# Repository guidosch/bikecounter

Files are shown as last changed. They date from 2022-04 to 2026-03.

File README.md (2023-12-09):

# BikeCounter  <!-- omit in toc -->



This repository contains the hardware and software components of a [PIR](https://en.wikipedia.org/wiki/Passive_infrared_sensor) based tracking device to monitor the usage of local bike trails. The data is sent over [LoRaWAN](https://de.wikipedia.org/wiki/Long_Range_Wide_Area_Network) to [TTN](https://www.thethingsnetwork.org/) and from there to a [Google Cloud](https://console.cloud.google.com) backend which stores the data and provides api endpoints for the data visualization web UI ([bikeCounterUI](https://github.com/guidosch/bikecounterUI)).

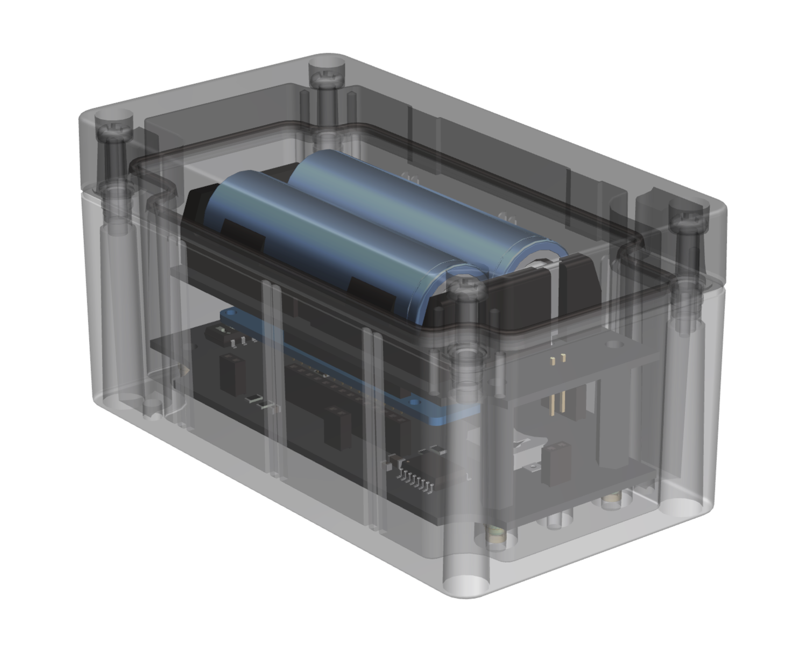
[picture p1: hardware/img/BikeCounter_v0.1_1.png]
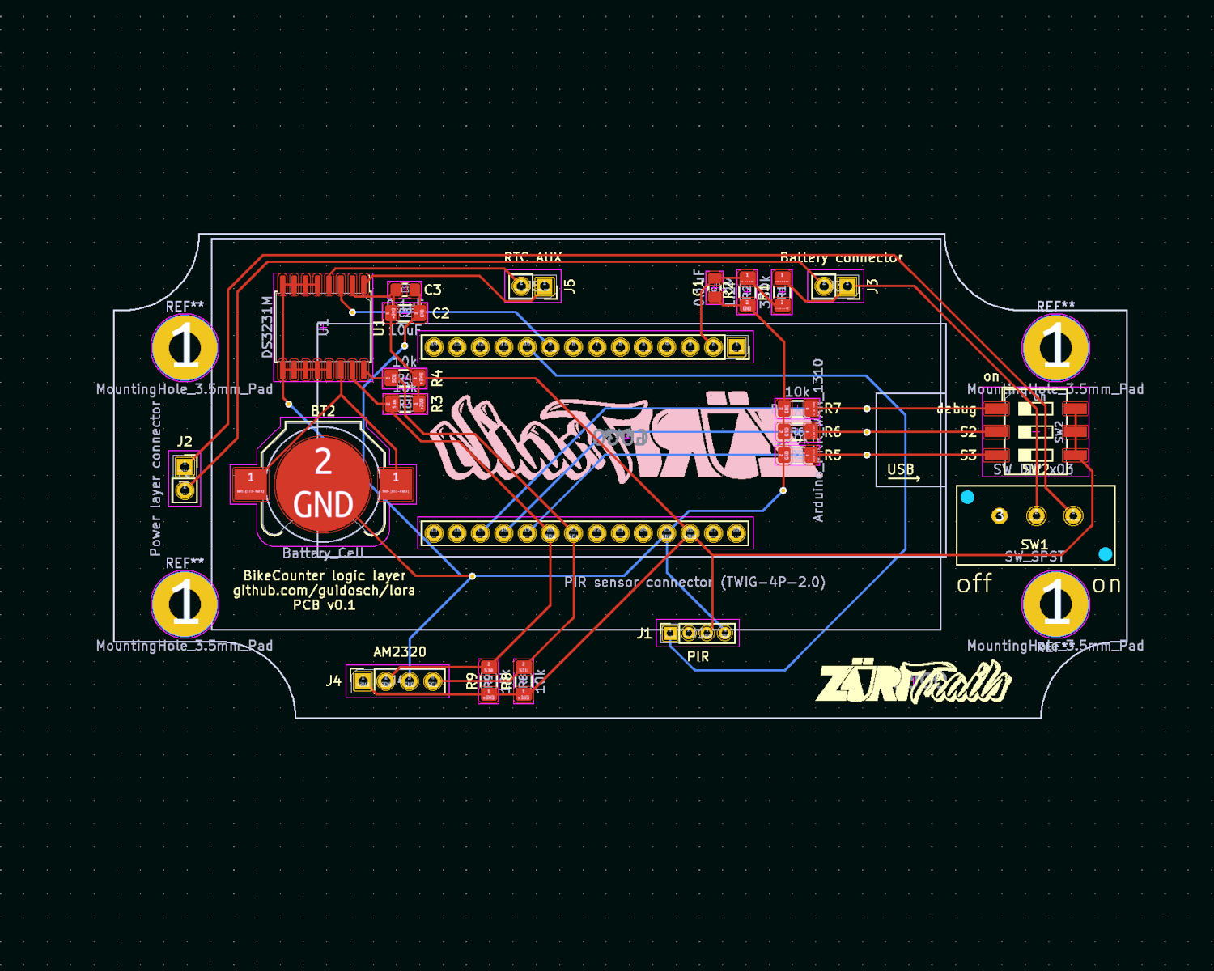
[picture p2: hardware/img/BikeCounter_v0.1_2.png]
 
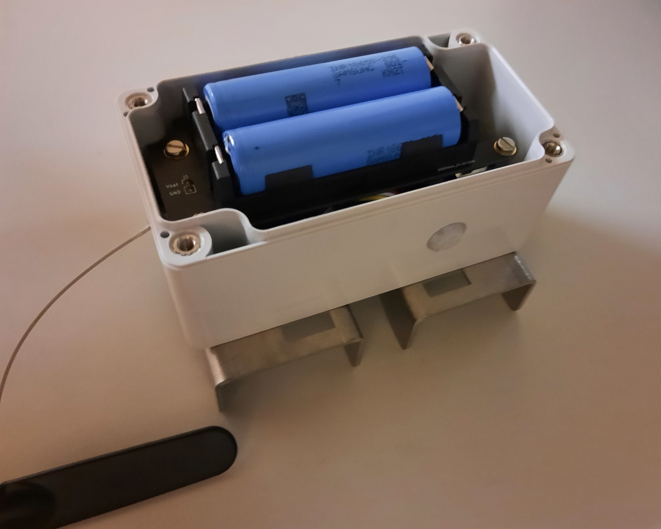
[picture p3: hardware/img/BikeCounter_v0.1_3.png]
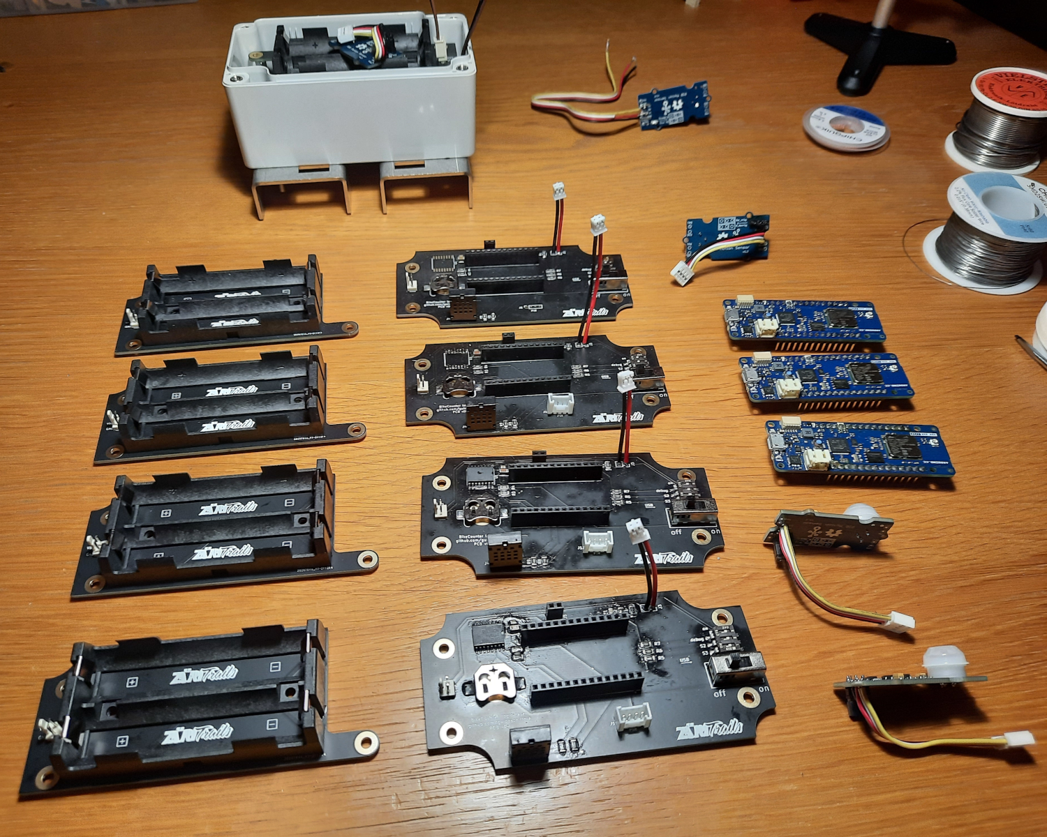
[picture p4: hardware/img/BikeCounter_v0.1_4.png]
 

The repository is divided into two main sections. The first one contains all the data regarding the hardware components and the second one holds the software code.

- [Hardware](#hardware)
- [Software](#software)
  - [Overview](#overview)
  - [BikeCounter](#bikecounter)
    - [Overall state machine](#overall-state-machine)
    - [Data package](#data-package)
    - [Time scheduler](#time-scheduler)
    - [Device configuration](#device-configuration)
    - [Unit tests](#unit-tests)
    - [To be aware of](#to-be-aware-of)
  - [TTN](#ttn)
  - [Google Cloud](#google-cloud)
- [Contributing](#contributing)
- [License](#license)

# Hardware

The core component of the device is an [Arduino MRKWAN 1310](https://docs.arduino.cc/hardware/mkr-wan-1310) which sits on the "logic layer" PCB. This PCB connects the micro controller to the sensors, the dip switches and the "power layer" PCB.

To detect the movement a PIR sensor from [Seeed Studio](https://www.seeedstudio.com/Grove-PIR-Motion-Sensor.html) is used and to monitor the internal environment of the device a temperature and humidity sensor from [Adafruit](https://www.adafruit.com/product/3721) was chosen.

The "power layer" PCB holds two rechargeable lithium-ion batteries (18650). This allows the device to run up to one year without exchanging the batteries.

The schematics and layout files of the PCBs as well as the BOM of the whole device can be found in the corresponding subfolder.

# Software

This Repository contains the code for the tracking device as well as the scripts running on the backend.

## Overview

```mermaid
flowchart LR;
  subgraph BikeCounter;
    Biker(Round) -->|infrared radiation| PIR-sensor;
    PIR-sensor -->|DIO| Arduino-MKRWAN-1310;
    Temp&Hum-sensor -->|I2C| Arduino-MKRWAN-1310;
    DIP-switches -->|DIO| Arduino-MKRWAN-1310;
  end; 
  subgraph TTN;   
    Arduino-MKRWAN-1310 -->|LoRaWAN| PayloadFormatter;
  end;  
  subgraph Google Cloud;
    PayloadFormatter -->|webhook| Cloud-function;
    Cloud-function --> firebase;
  end;
```

## BikeCounter

There are two versions of the main BikeCounter software. The **light** version is a simple and basic implementation of the needed functionality. The **pro** version has extended features that allow it to take track of time as well as its environnement conditions.

(Due to the fact that the light version is almost obsolete only the pro version will be explained in more detail.)

### Overall state machine

```mermaid
stateDiagram-v2
    m1: main loop
    [*] --> Setup
    Setup --> m1
    state m1 {
      state if_motion <<choice>>
      s0: motion detected ?
      s1: store information in variable      
      s2: timer called
      s3: threshold reached ?
      state if_threshold <<choice>>
      s4: send data
      state if_downlink <<choice>>
      s5: downlink received ?
      s6: correct rtc drift
      
      [*] --> s0
      s0 --> if_motion
      if_motion --> s1: true
      if_motion --> s2: false
      s2 --> s4
      s1 --> s3
      s3 --> if_threshold
      if_threshold --> deepSleep: false
      if_threshold --> s4: true
      s4 --> s5
      s5 --> if_downlink
      if_downlink --> deepSleep: false
      if_downlink --> s6: true
      s6 --> deepSleep
      deepSleep --> [*]
    }
```

After the main loop finishes the device goes into a deepSleep mode. From there the PIR sensor or the rtc timer can wake it back up and trigger the main loop again.

### Data package

The payload size of one single LoRaWAN data package is restricted to 51 bytes. To avoid multi-package messages and to reduce transmission time an optimized information transmission protocol was developed.

The dataPackage class handles all the information conversion and encoding. A detailed documentation of the protocol can be found in the dataPackage.xlsx file.

**Payload encoding**

| address<br>bits | 0-7<br>[8] | 8-11<br>[4] | 12-15<br>[4] | 16-18<br>[3] | 19-23<br>[5] | 24-27<br>[5] | 28-30<br>[3] | 31-54<br>[24] | 55-57<br>[3] | 58-62<br>[5] | 63-408<br>[6/7/8/9/10] |
| --- | --- | --- | --- | --- | --- | --- | --- | --- | --- | --- | --- |
| **content** | count | software version | hardware version | status index | battery voltage | temperature  | humidity | device time | interval index | hour of the day | offset minutes array |

The data type size of the offset array depends on the selected interval.

### Time scheduler

During the night as well as the cold seasons of the year the data transmission interval can be adjusted to save energy and transmission time. The timeScheduler class provides all the necessary methods to accomplish such a dynamic behavior.

### Device configuration

The configuration information to establish a connection to the TTN (AppEUI and AppKey) is saved to the flash memory of the Arduino MKRWAN 1310. The `writeConfigToFlash.ino` script saves a new configuration to the memory.

### Unit tests

This repository contains serval unit tests for the dataPackage and the timeScheduler class. The tests are written using the [Google Test](https://google.github.io/googletest/) framework. A cMake configuration for local testing is provided as well as an automated CI pipeline for the master branch. The `runTestsLocal.sh` script executes all the commands needed to run the unit tests locally.

### To be aware of

- The LoRa module is very timing sensitive. That is the reason there are so many delays in the code to give it enough time to wait for messages and to response.

- The first time the (deep)sleep method is called, it re-initializes the RTC to a wrong value. To fix this issue the first iteration of the main loop puts the device into the sleep mode for a short period of time and resets the RTC in the next loop.

## TTN

The message from the device gets over LoRaWAN to the TTN server where a uplink payload formatter parses the data bytes to a human readable JavaScript object. The server then triggers a webhook and passes the data object to the Google Cloud function API endpoint.

The downlink message with the time drift information will also be parsed by the payload formatter defined in TTN.

The up/down-link payload formatter scripts are stored in the TTN subfolder.

## Google Cloud

The triggered cloud function evaluates the data object sent from TTN and saves it to the Firebase database. Depending on the difference between the local time of the device and the server time it schedules a downlink message to correct the internal device time.

There are also cloud functions that provide an API endpoint for the web UI ([bikeCounterUI](https://github.com/guidosch/bikecounterUI)) to visualize the stored data.

# Setup IDE and compile code
Download and install: `arduino-cli` which is available for brew or apt-get. Install the `arduino` extension for VSCode and adjust the `arduino.path` in the extension settings and point to your arduino-cli installation folder.

Add the following libraries to your installation: `arduino-cli lib install [libName]`

- Needed libraries:
  - MKRWAN@1.1.0
  - RTCZero@1.6.0
  - SPI.h --> already preinstalled
  - SparkFun SPI SerialFlash Arduino Library@1.0.3
  - Arduino Low Power@1.2.2
  - Adafruit Unified Sensor@1.1.6

Copy and adjust the `.vscode/c_cpp_properties.json_example` for your platform. You have to adjust the place where arduino-cli downloads the libraries as they are needed by the IDE

Compile: `arduino-cli compile --fqbn arduino:samd:mkrwan1310 BikeCounterPro.ino`

Deploy: `arduino-cli upload -p [/dev/yourdevice] --fqbn arduino:samd:mkrwan1310 BikeCounterPro.ino`

Hint: `arduino-cli board list` will show the USB port, where the device is connected

# Contributing

Pull requests are welcome. For major changes, please open an issue first to discuss what you would like to change.

Please make sure to update the tests as appropriate.

# License

This project is licensed under [CC0-1.0](LICENSE)

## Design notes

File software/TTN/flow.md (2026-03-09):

# Flow from Device to TTN

1. Device sends data to TTN via LoRaWAN as uplink message encoded in bytes.
2. TTN receives the uplink message and processes it via the payload formatter (uplink)
3. The result is forwarded to GCP cloud function: See uplink_example.js for an example of the processed data.

# Flow from TTN to Device

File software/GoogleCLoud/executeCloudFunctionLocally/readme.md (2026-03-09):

# Execute Cloud Function Locally

## Setup

1. **Install dependencies:**
   ```bash
   npm install
   ```

2. **Download the Firebase/Google Cloud service account key:**
   - Go to the [Google Cloud Console](https://console.cloud.google.com/)
   - Navigate to **IAM & Admin → Service Accounts**
   - Select your project and the service account used by your Cloud Function
   - Click **Keys → Add Key → Create new key → JSON**
   - Save the downloaded file as `service-account-key.json` in this directory

3. **Run the function locally:**
   ```bash
   npm run start
   ```
   The function will be available at `http://localhost:8080/`

4. **Test with a sample request:**
Use the requests.http file which contains a test request (need vs code plugin: 
humao.rest-client). May adjust the playload by extacting it from the GCP functions log and paste it into file `payload-example.json`

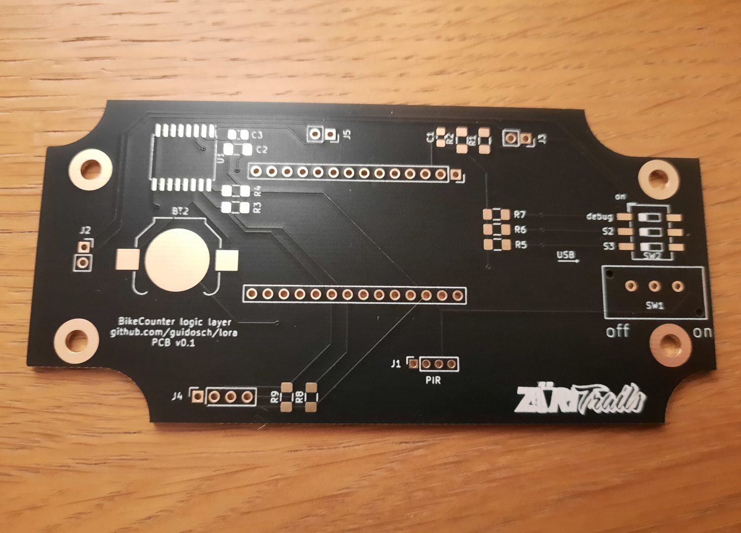
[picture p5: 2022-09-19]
hardware/img/BikeCounter_v0.1_5.png

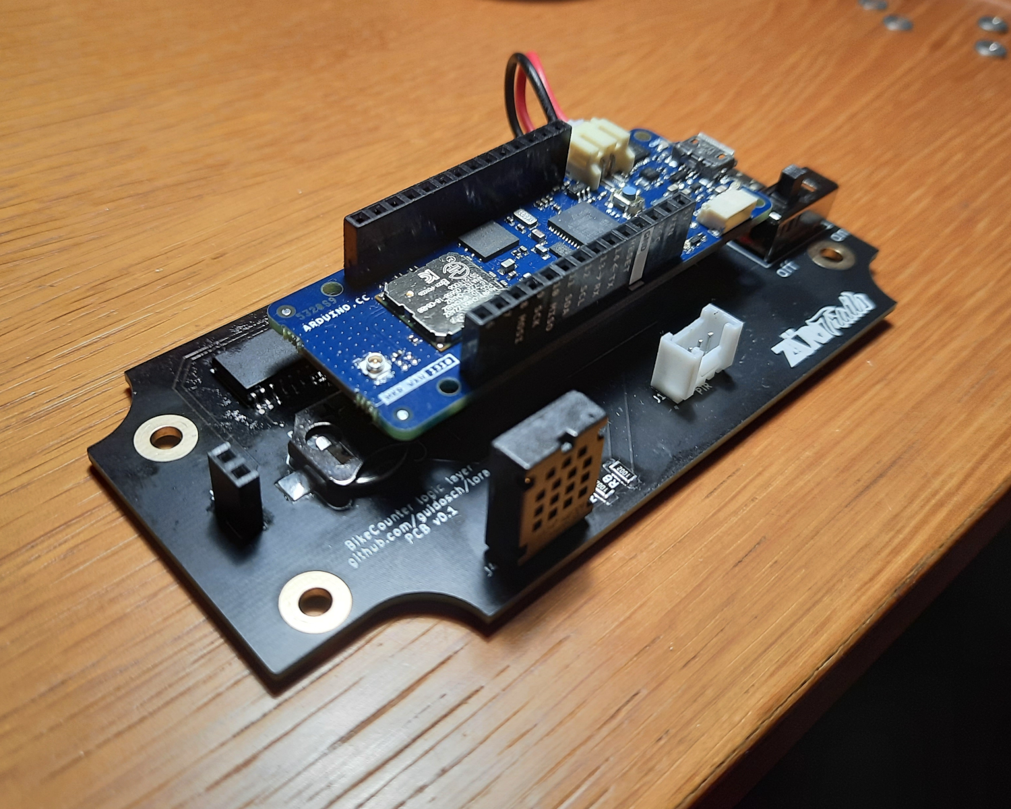
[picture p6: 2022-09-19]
hardware/img/BikeCounter_v0.1_6.png

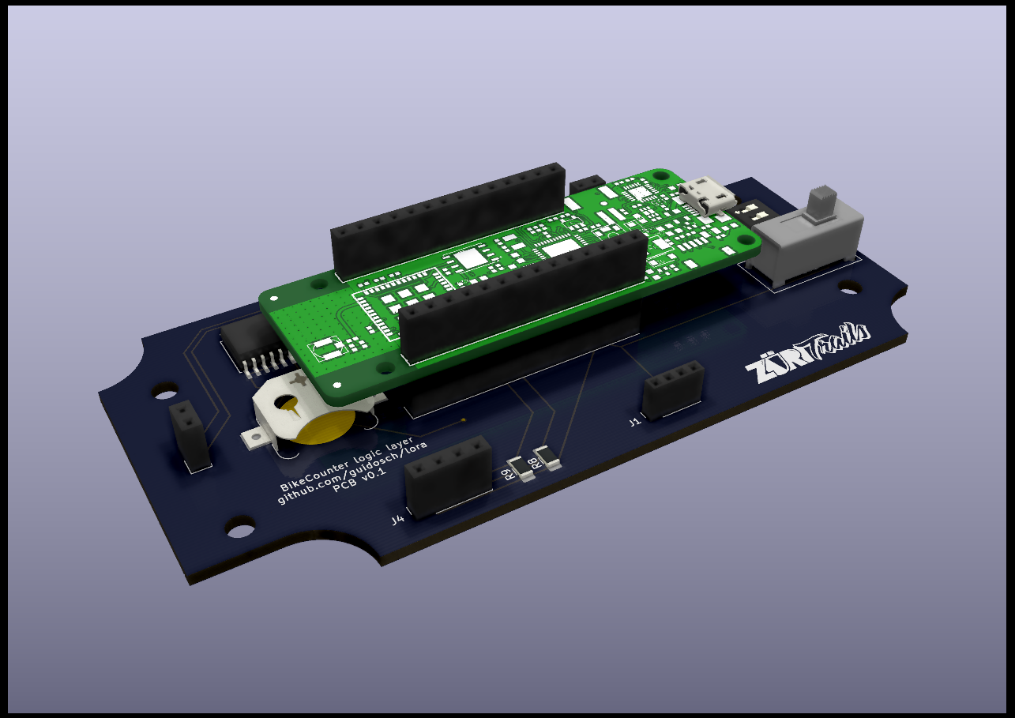
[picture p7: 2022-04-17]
hardware/PCB/LogicLayer/BikeCounter_LogicLayer_v0.1_r1_p1.png

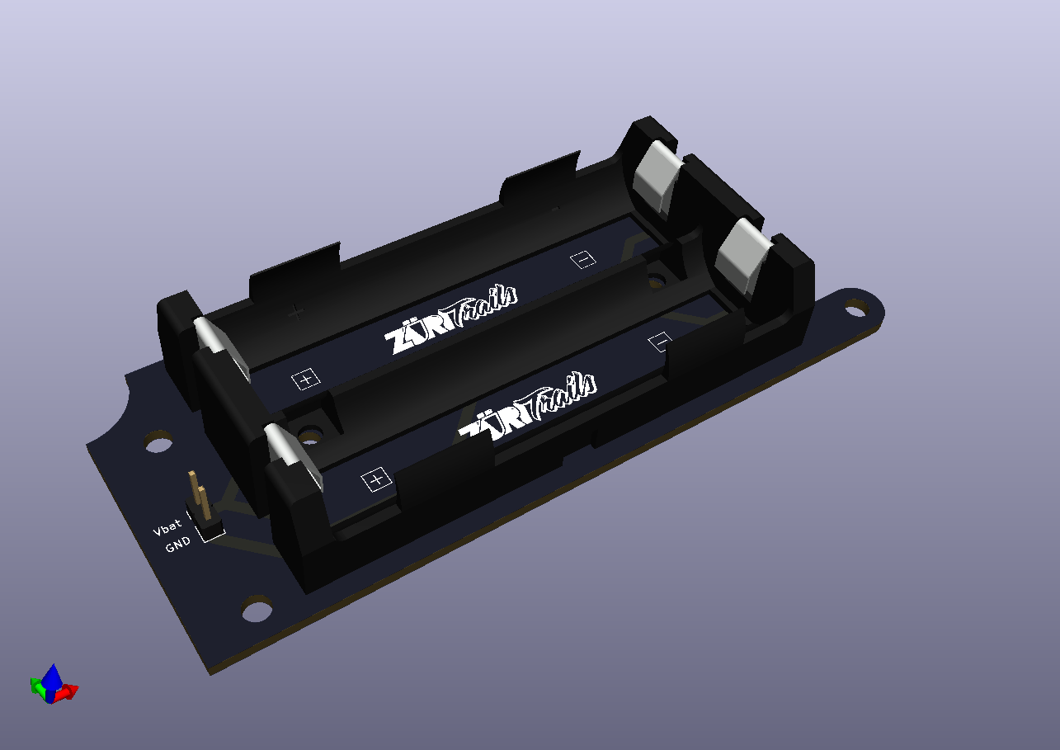
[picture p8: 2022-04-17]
hardware/PCB/PowerLayer/BikeCounter_PowerLayer_v0.1_r1_p1.png

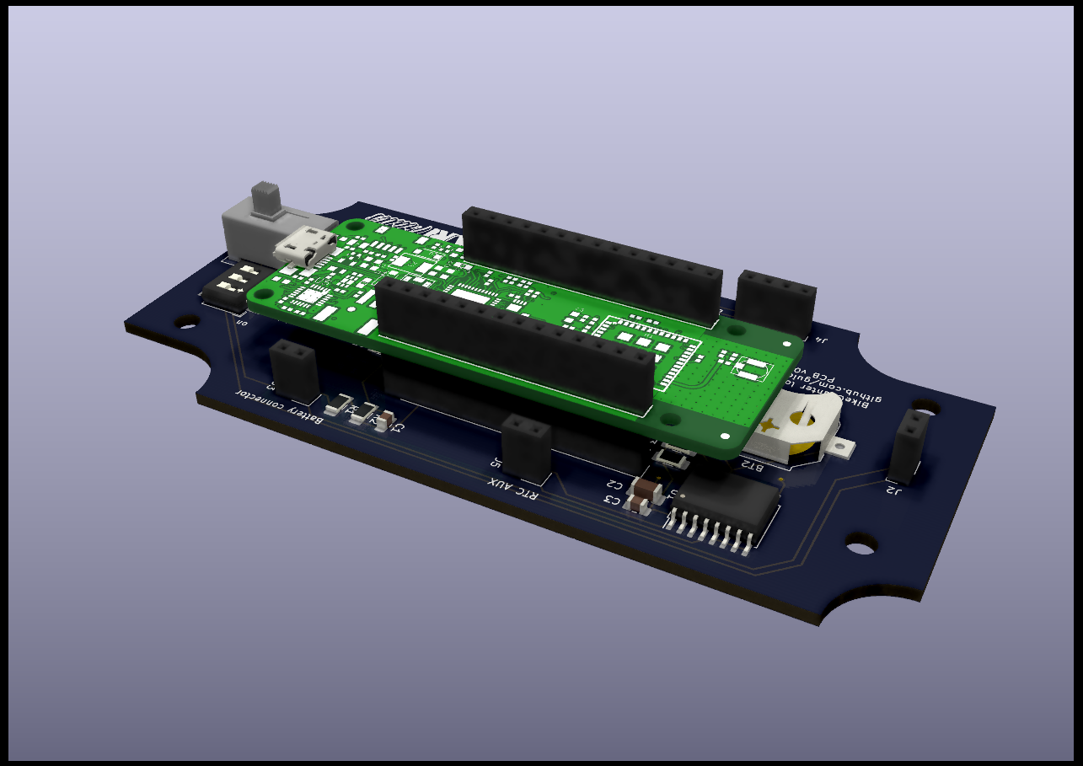
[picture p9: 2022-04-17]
hardware/PCB/LogicLayer/BikeCounter_LogicLayer_v0.1_r1_p3.png

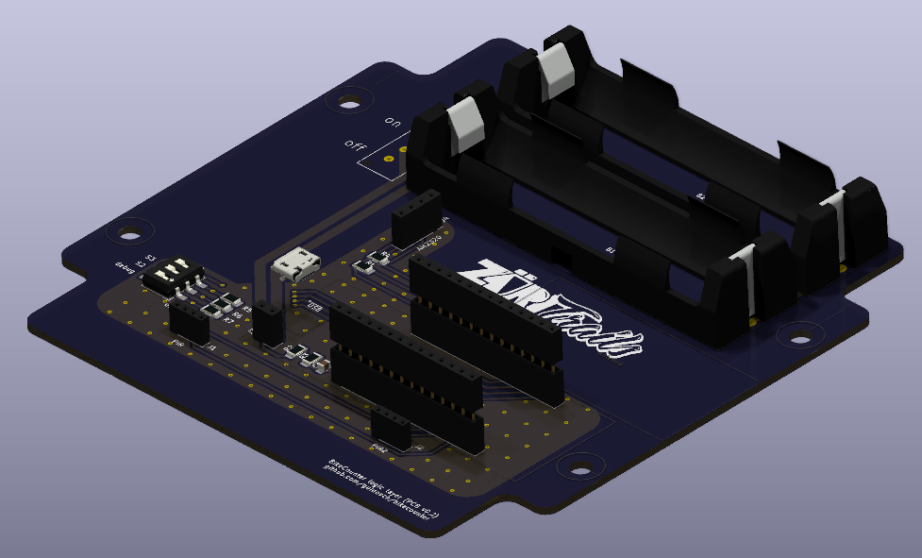
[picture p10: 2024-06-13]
hardware/PCB/SingleBoard/BikeCounter_SingleBoard.png

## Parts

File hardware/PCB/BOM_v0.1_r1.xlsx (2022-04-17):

Id | Designator | Package | Quantity | Designation | Price |  | Link 1 | Link 2 | Link 3
1 | R5,R9,R8,R7,R6,R4,R3 | R_1206_3216Metric_Pad1.42x1.75mm_HandSolder | 7 | 10k | 0.65 CHF | 4.55 CHF | https://www.mouser.ch/ProductDetail/Bourns/CHP1206AFX-1002ELF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
2 | BT2 | BatteryHolder_Keystone_3000_1x12mm | 1 | Battery_Cell | 0.62 CHF | 0.62 CHF | https://www.mouser.ch/ProductDetail/Keystone-Electronics/3000?qs=sGAEpiMZZMvxX9Q80wbhCYuFHF%2FXyzv7
3 | A1 | Arduino_MKR_WAN_1310 | 1 | Arduino_MKR_WAN_1310 | 47.17 CHF | 47.17 CHF | https://www.distrelec.ch/de/arduino-mkr-wan-1310-arduino-abx00029/p/30163021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
4 |  | Antenne | 1 |  | 5.18 CHF | 5.18 CHF | https://www.distrelec.ch/de/gsm-antenne-2g-3g-4g-fl-klebebefestigung-arduino-x000016/p/30101972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
5 | J1 | PinSocket_1x04_P2.00mm_Vertical | 1 | PIR sensor connector (TWIG-4P-2.0) | 0.17 CHF | 0.17 CHF | https://www.seeedstudio.com/Grove-Universal-4-pin-connector.html
6 | J5 | PinSocket_1x02_P2.54mm_Vertical | 1 | RTC AUX | 0.77 CHF | 0.77 CHF | https://www.mouser.ch/ProductDetail/Harwin/M20-7820242?qs=WS5Jv%252B%252Bx1qUrSLY%252BudG7mQ%3D%3D
7 | SW1 | Switch_MHS12204 | 1 | SW_SPST | 1.06 CHF | 1.06 CHF | https://www.mouser.ch/ProductDetail/TE-Connectivity-Alcoswitch/MHS12204?qs=x%2FgbKjZ2T%2FPUluB%2FWhqq0Q%3D%3D
8 | J2 | PinSocket_1x02_P2.54mm_Vertical | 1 | Power layer connector | 0.77 CHF | 0.77 CHF | https://www.mouser.ch/ProductDetail/Harwin/M20-7820242?qs=WS5Jv%252B%252Bx1qUrSLY%252BudG7mQ%3D%3D
9 | R2 | R_1206_3216Metric_Pad1.42x1.75mm_HandSolder | 1 | 1.2M | 0.21 CHF | 0.21 CHF | https://www.mouser.ch/ProductDetail/YAGEO/RT1206FRE071M2L
10 | R1 | R_1206_3216Metric_Pad1.42x1.75mm_HandSolder | 1 | 330k | 0.13 CHF | 0.13 CHF | https://www.mouser.ch/ProductDetail/Susumu/RG3216P-3303-D-T5?qs=nCAm%252BcMdy9yoDulF%2FHMGvA%3D%3D
11 | C1,C3 | C_0805_2012Metric_Pad1.15x1.40mm_HandSolder | 2 | 0.1uF | 0.12 CHF | 0.24 CHF | https://www.mouser.ch/ProductDetail/KEMET/C0805C104K5RAC7411 | https://www.mouser.ch/ProductDetail/Murata-Electronics/GCJ31CD7YA106KE02L?qs=DPoM0jnrROWHhAptP6iQ0Q%3D%3D
12 | U1 | SOIC-16W_7.5x10.3mm_P1.27mm | 1 | DS3231M | 10.70 CHF | 10.70 CHF | https://www.mouser.ch/ProductDetail/Maxim-Integrated/DS3231SN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 | https://www.digikey.ch/de/products/detail/analog-devices-inc-maxim-integrated/DS3231SN/1197576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
13 | SW2 | SW_DIP_SPSTx03_Slide_6.7x9.18mm_W8.61mm_P2.54mm_LowProfile | 1 | SW_DIP_x03 | 0.68 CHF | 0.68 CHF | https://www.mouser.ch/ProductDetail/CTS-Electronic-Components/219-3LPS?qs=6E8igxPflKd33iZv5eBb9Q%3D%3D
14 | C2 | C_1206_3216Metric_Pad1.33x1.80mm_HandSolder | 1 | 10uF | 1.35 CHF | 1.35 CHF | https://www.mouser.ch/ProductDetail/TDK/C3216X6S2A106K160AC
15 | B1 | BatteryHolder_Keystone_1049_2x18650 | 1 | Keystone_1049 | 5.83 CHF | 5.83 CHF | https://www.mouser.ch/ProductDetail/Keystone-Electronics/1049?qs=%2F7TOpeL5Mz78b0pqEFIl5w%3D%3D
16 | J1 | PinHeader_1x02_P2.54mm_Vertical | 1 | Logic layer connection | 0.38 CHF | 0.38 CHF | https://www.mouser.ch/ProductDetail/Samtec/TSW-102-19-L-S?qs=rU5fayqh%252BE00YQR0mRO7Kw%3D%3D
17 |  | PinSocket_1x14_P2.54mm_Vertical | 2 |  | 1.54 CHF | 3.08 CHF | https://www.mouser.ch/ProductDetail/Harwin/M20-7821446?qs=Jph8NoUxIfX%2FjYzLF0Toqw%3D%3D
18 |  | Casing | 1 |  | 18.63 CHF | 18.63 CHF | https://www.mouser.ch/ProductDetail/Hammond/1554D2GYSL?qs=8GnAp0dDS0IydYdPUJXAZg%3D%3D | https://www.mouser.ch/ProductDetail/Hammond/1554D2GYCL?qs=Tc%252BHE9vUsnsrPWXgdbccVQ%3D%3D | https://www.digikey.ch/de/products/detail/1554D2GYSL/HM3459-ND/2359931?itemSeq=385358295
19 |  | Mounting | 3 |  | 0.54 CHF | 1.62 CHF | https://www.mouser.ch/ProductDetail/Wurth-Elektronik/971220321?qs=wr8lucFkNMXKaoSdjnz3%252Bg%3D%3D
20 |  | Grove PIR sensor | 1 |  | 12.60 CHF | 12.60 CHF | https://www.distrelec.ch/de/grove-pir-bewegungssensor-seeed-studio-101020020/p/30069806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
21 |  | AM2320 | 1 |  | 4.52 CHF | 4.52 CHF | https://www.distrelec.ch/de/digitaler-temperatur-und-feuchtigkeitssensor-am2320-5v-adafruit-3721/p/30139175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
22 |  | Power Layer PCB | 1 |  | 4.78 | 4.78 CHF |  | JLCPCB
23 |  | Logic Layer PCB | 1 |  | 4.88 | 4.88 CHF |  | JLCPCB
24 |  | USB Kabel | 1 |  | 2.02 CHF | 2.02 CHF | https://www.reichelt.com/ch/de/usb-2-0-kabel-a-stecker-auf-90-micro-b-stecker-1-8-m-goobay-95343-p286822.html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
25 |  | Akku | 2 |  | 12.95 CHF | 25.90 CHF | https://www.conrad.ch/de/p/samsung-inr18650-29e-spezial-akku-18650-flat-top-hochtemperaturfaehig-li-ion-3-6-v-2900-mah-2239492.html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
 |  |  |  |  |  | 157.85 CHF

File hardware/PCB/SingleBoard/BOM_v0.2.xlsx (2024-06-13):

Id | Designator | Package | Quantity | Designation | Price |  | Link 1 | Link 2 | Link 3
1 |  | PCB | 1 | JLC PCB (20 Stk.) | 3.56 CHF | 3.56 CHF
2 | A1 | Arduino_MKR_WAN_1310 | 1 | Arduino_MKR_WAN_1310 | 39.44 CHF | 39.44 CHF | https://www.mouser.ch/ProductDetail/Arduino/ABX00029?qs=rkhjVJ6%2F3EJR8pfu7j970Q%3D%3D
3 | B1,B2 | BatteryHolder_Keystone_1043_1x18650 | 2 |  | 2.15 CHF | 4.30 CHF | https://www.mouser.ch/ProductDetail/Keystone-Electronics/1043?qs=%2F7TOpeL5Mz6j%2FnxeOA1rsg%3D%3D
 | C1 | Capacitor_SMD:C_0805_2012Metric_Pad1.18x1.45mm_HandSolder | 2 | 0.1uF | 0.06 CHF | 0.11 CHF | https://www.mouser.ch/ProductDetail/KEMET/C0805C104K5RAC7411 | https://www.mouser.ch/ProductDetail/Murata-Electronics/GCJ31CD7YA106KE02L?qs=DPoM0jnrROWHhAptP6iQ0Q%3D%3D
 | R1,R4,R5,R6,R7 | Resistor_SMD:R_1206_3216Metric_Pad1.30x1.75mm_HandSolder | 5 | 10k | 0.19 CHF | 0.93 CHF | https://www.mouser.ch/ProductDetail/Bourns/CHP1206AFX-1002ELF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
 | R2 | Resistor_SMD:R_1206_3216Metric_Pad1.30x1.75mm_HandSolder | 1 | 330k | 0.12 CHF | 0.12 CHF | https://www.mouser.ch/ProductDetail/Susumu/RG3216P-3303-D-T5?qs=nCAm%252BcMdy9yoDulF%2FHMGvA%3D%3D
 | R3 | Resistor_SMD:R_1206_3216Metric_Pad1.30x1.75mm_HandSolder | 1 | 1.2M | 0.14 CHF | 0.14 CHF | https://www.mouser.ch/ProductDetail/YAGEO/RT1206FRE071M2L
 | SW1 | General_TM:Switch_MHS12204 | 1 | SW_SPST | 0.73 CHF | 0.73 CHF | https://www.mouser.ch/ProductDetail/TE-Connectivity-Alcoswitch/MHS12204?qs=x%2FgbKjZ2T%2FPUluB%2FWhqq0Q%3D%3D
 | SW2 | Button_Switch_SMD:SW_DIP_SPSTx03_Slide_6.7x9.18mm_W8.61mm_P2.54mm_LowProfile | 1 | SW_DIP_x03 | 0.51 CHF | 0.51 CHF | https://www.mouser.ch/ProductDetail/CTS-Electronic-Components/219-3LPS?qs=6E8igxPflKd33iZv5eBb9Q%3D%3D
 | J1,J2 | Connector_PinSocket_2.00mm:PinSocket_1x04_P2.00mm_Vertical | 2 | PIR, PIR 2 | 0.10 CHF | 0.20 CHF | https://www.seeedstudio.com/Grove-Universal-4-pin-connector.html
 |  | PinSocket_1x14_P2.54mm_Vertical | 2 | Board connector | 1.93 CHF | 3.86 CHF | https://www.mouser.ch/ProductDetail/Harwin/M20-7821446?qs=Jph8NoUxIfX%2FjYzLF0Toqw%3D%3D
 |  | Grove PIR sensor | 1 |  | 7.06 CHF | 7.06 CHF | https://www.distrelec.ch/de/grove-pir-bewegungssensor-seeed-studio-101020020/p/30069806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
 |  | AM2320 | 1 |  | 6.65 CHF | 6.65 CHF | https://www.distrelec.ch/de/digitaler-temperatur-und-feuchtigkeitssensor-am2320-5v-adafruit-3721/p/30139175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
 |  | Antenne | 1 |  | 21.52 CHF | 21.52 CHF | https://www.mouser.ch/ProductDetail/712-ANT-8-9-SPNF2
 |  | Adapter | 1 |  | 15.23 CHF | 15.23 CHF | https://www.mouser.ch/ProductDetail/523-242114
 |  | Kabel | 1 |  | 8.10 CHF | 8.10 CHF | https://www.mouser.ch/ProductDetail/RF-Solutions/CBA-UFLSMA15?qs=UkDUCjYnTB3hw8AxXa9rig%3D%3D
 |  | Casing 135x135x60mm | 1 |  | 18.50 CHF | 18.50 CHF | https://www.distrelec.ch/de/kunststoffgehaeuse-mit-durchsichtigem-deckel-universal-135x135x60mm-hellgrau-polycarbonat-ip66-ip68-ik07-rnd-rnd-455-01382/p/30375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
 |  | Schrauben M3.5 | 4 |  | 0.01 CHF | 0.05 CHF | https://www.distrelec.ch/de/kreuzschraube-flachkopf-blech-pozidriv-pz2-mm-5mm-packung-100-stueck-rnd-rnd-610-00627/p/30172862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
 |  | Akku | 2 | 2.6Ah | 18.32 CHF | 36.64 CHF | https://www.distrelec.ch/de/akku-li-ion-18650-6v-6ah-ansmann-1307-0000/p/30103796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
 |  |  |  |  |  | 164.09 CHF
 |  | Akku alternative | 1 | 3.5Ah | 23.32 CHF | 23.32 CHF | https://www.distrelec.ch/de/akku-li-ion-18650-6v-5ah-ansmann-1307-0001/p/30152666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
 |  | Akku alternative | 1 | 3.4Ah (USB ladebuchse) | 21.90 CHF | 21.90 CHF | https://www.distrelec.ch/de/akku-mit-usb-ladebuchse-li-ion-18650-6v-4ah-ansmann-1307-0003/p/30264499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
 |  |  |  | Aufstellung für 5 Stück | 746.97 CHF
 |  |  |  | Aufstellung für 10 Stück | 1567.43 CHF

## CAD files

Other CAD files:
hardware/PCB/CAD_files/BikeCounter.prt
hardware/PCB/CAD_files/BikeCounter_PowerLayer.prt

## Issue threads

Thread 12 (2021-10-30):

Power consumtion measurement setup

MeierTobias, 2021-10-30:
Build a setup to measure the power consumtion.
(Example measurement resistor sizes: 0.05; 0.1; 0.5; 1; 10 Ohm)

MeierTobias, 2023-12-09:
The power consumption is at an acceptable level at the moment so I would say we don't need this for now.

Closed 2023-12-09.

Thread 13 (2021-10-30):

Floating interrupt pin (PIR-sensor)

MeierTobias, 2021-10-30:
Does the bug still exist after the improvements?
If yes: Add an external pull-down resistor (ex. 10kOhm)

guidosch, 2021-10-31:
May be we could also try to power the PIR-sensor over a GPIO and powercycle if we encouter the problem again.

MeierTobias, 2021-10-31:
>
>
> May be we could also try to power the PIR-sensor over a GPIO and powercycle if we encouter the problem again.

I've allready implemented this functionality in commit 56dffbbf8f9618892b4d479a88fb53bb3e4537cf
You can now specify the GPIO pin to power the sensor. (currently pin 2)
I also found an internal pull-down resistor flag. I thought that the MKR 1310 only has internal pull-up resistors. But its worth a try :)

This issue was meant as a "follow up" but I think we can close it and reopen a new one if the problem still exists.

guidosch, 2021-10-31:
First device is resoldered and uses the new code with the power pin. Works so far nicely.

MeierTobias, 2021-10-31:
Wuhuu 🚲

Closed 2021-10-31.

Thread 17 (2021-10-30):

Add the humidity sensor to the pro version

MeierTobias, 2021-10-30:
- [x] add code to measure the humidity and temperatur
- [x] implement the data package
- [x] change the schematics
- [x] change the pcb

Closed 2021-12-04.

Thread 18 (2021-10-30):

Measure Li-Ion battery decharge curve

MeierTobias, 2021-10-30:
- [ ] Measure the decharge curve
- [ ] Calculate polynomial coeff.

guidosch, 2022-10-15:
Decharge curve of the "antennentrail-1" device over summer period 2022.

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

guidosch, 2022-10-20:
Mapping from value to charging level: Ideas
https://stackoverflow.com/questions/13399821/data-structures-that-can-map-a-range-of-keys-to-a-value
https://greensock.com/docs/v3/GSAP/UtilityMethods/mapRange()

Closed 2023-12-09.

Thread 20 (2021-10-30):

Order all the parts for the BikeCounterPro prototype

MeierTobias, 2021-10-30:
- [x] Electronic parts
- [x] PCB
- [x] Casing and mounting
- [x] Resistor for power measuremen
- [x] Resistor for PIR-Sensor adjustment

Closed 2021-12-14.

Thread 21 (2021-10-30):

Determen measurement accuracy

MeierTobias, 2021-10-30:

guidosch, 2022-01-06:
Etwas ist mir gestern noch aufgefallen. Wir hatten ja im Serial Log einige mehrfach Zählungen vom PIR Sensor. Könnte es sein, dass im Retrigger Mode der PIR Sensor zu lange auf "High" ist und dann die CPU mehrfach aufweckt? Oder braucht es immer einen Wechsel von "Low" auf "High" damit ein Count gezählt wird?

MeierTobias, 2022-01-06:
Es braucht immer einen wechsel von low auf high (rising edge) damit der Interrupt ausgeführt wird. Ich habe aber auch schon festgestellt, dass beim Senden der Daten der PIR-Sensor ausschlägt. Zuerst dachte ich es sei einfach Rauschen auf dem interrupt Pin aber die Messung mit dem Oszilloskop hat gezeigt das der Sensor in diesem Moment eine saubere Flanke asugibt.

Ich habe auch einmal bemerkt, dass die 3.3V Output Spannung beim Senden zusammen bricht. (Manchmal bis auf 2.7V herunter)
Habe dies versucht mit einem Kondensator zu überbrücken hat aber leider nichts genützt.
Da wir die Spannungsversorgung des PIR-Sensors jetzt ja über einen DO-Pin machen, könnten wir den Sensor vor dem Senden ausschalten und danach wieder ein. Das könnte das Problem lösen.
Ich werde das im neuen Prototypen einmal testen.

MeierTobias, 2022-01-06:
Für die Bestimmung der Messunsicherheit könnten wir neben den Testfahrten auch drei oder vier Zähler an der selben Stelle montieren und die Abweichungen untereinander vergelichen.

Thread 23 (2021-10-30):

Add on/off switch to pcb

MeierTobias, 2021-10-30:

MeierTobias, 2021-12-04:
The power layer and the logic layer are now on two separate boards. This makes the issue obsolete.

Closed 2021-12-04.

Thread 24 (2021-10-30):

Implement Lora downlink

MeierTobias, 2021-10-30:
- ensures that the message was transmitted
- pass configuration to device

guidosch, 2022-01-06:
Idea is to use the downlink to check if the message was received by any gateway. If the device does not receive a "ACK" it will retry a few times (not endless du to battery drain).

May collect failed messages as counter and add to health data to get a idea how many times it does not work. Could also be determined by the msg. send intervall...

MeierTobias, 2022-03-09:
modem.endPacket(true);

MeierTobias, 2022-04-13:
I tested and implemented the modem.endPacket(true); method into the pro version.
It works well but I saw some uplink messages which were sent in a very short time span (20 sec.) I want to check if this has something to do with the "ACK" downlink

MeierTobias, 2022-09-08:
implemented and tested with #48

Closed 2022-09-08.

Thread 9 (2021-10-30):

Defined state of unsued pins

MeierTobias, 2021-10-30:
Set all the unsued digital pins to a defined state to avoid leakage. (save power)
``` c++
pinMode(pin, OUTPUT);
digitalWrite(pin, LOW);
```

Closed 2021-10-30.

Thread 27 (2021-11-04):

Timer intervall adjustment during the night

MeierTobias, 2021-11-04:

MeierTobias, 2021-11-10:
In the same implementation:
Fix the "houre of the day" after midnight problem.
``` c++
If((newAlarmTime.day > now.day) && (!lastTimerFlag))
{
newAlarmTime = "23:50";
lastTimerFlag = true;
}
else
{
lastTimerFlag = false;
}
```

Closed 2022-04-13.

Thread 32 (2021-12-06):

Implement watchdog

guidosch, 2021-12-06:
See https://content.arduino.cc/assets/mkr-microchip_samd21_family_full_datasheet-ds40001882d.pdf for spec. details.

guidosch, 2022-11-09:
https://github.com/adafruit/Adafruit_SleepyDog

guidosch, 2022-11-09:
The mrkwan 1310 has a HW watchdog and the SleepyDog supports the board also with sleep support.

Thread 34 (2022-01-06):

Deactivate PIR-Sensor during data transmision

MeierTobias, 2022-01-06:
Follow up from [https://github.com/guidosch/lora/issues/21#issuecomment-1006514259](https://github.com/guidosch/lora/issues/21#issuecomment-1006514259)

guidosch, 2022-01-06:
Great idea!

MeierTobias, 2022-01-06:
Here's the data sheet of the PIR-Sensor for further investigation of this problem.
[https://files.seeedstudio.com/wiki/Grove_PIR_Motion_Sensor/resources/Twig_-_BISS0001.pdf](https://files.seeedstudio.com/wiki/Grove_PIR_Motion_Sensor/resources/Twig_-_BISS0001.pdf)
(Graph of the different trigger modes on page 2 and 3)

Closed 2022-01-10.

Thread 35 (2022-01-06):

Build fake PIR-Sensor

MeierTobias, 2022-01-06:
Solder a simple push button to a connector used for the PIR-Sensor to simulate the output of the sensor.
This may help to determine if the wrong triggered interrupts are caused by the PIR board or if it's an Arduino problem.
Also helps to simulate counts while debugging other stuff.

Closed 2022-01-10.

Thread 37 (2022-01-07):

Battery level calculation

MeierTobias, 2022-01-07:
Move the battery level calculation from the device to the server (ex. payload formatter). The MC only transmitts the battery voltage. With this change we are able to update the decharge curve parameters of the battery without reuploading the code to every MC.

Closed 2022-01-10.

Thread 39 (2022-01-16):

Indication LED

MeierTobias, 2022-01-16:
With the new pcb design the battery covers the onboard LED of the arduino and its very hard to see if it blinks.
To do:
Add an externel LED for better visibility to the pcb.

Closed 2024-03-22.

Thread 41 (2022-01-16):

Add battery type to device payload to support different discharging curves

guidosch, 2022-01-16:
I found some batteries at home which we could use as well but they may have a different discharging behavior. Lets send the battery type as well so we can implement several batteryLevel calculations in the payload formatter.

MeierTobias, 2022-04-13:
The battery type is now a part of the hw-version index

Closed 2022-04-13.

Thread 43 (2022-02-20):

Auto retrigger bug from PIR sensor is still issue

guidosch, 2022-02-20:
The latest software revision in the field still has the auto retrigger bug that auto counts many gost riders. The difference to the initial version is, that it stopped after 2000 counts  (50 msg. à 40 counts). First occurence:

first: 2022-02-17T01:01:43.966894717Z

dann ca. alle 10min

last: 2022-02-17T09:24:00.403713939Z

It looks like that it came back to normal operation after 2x 1000 error bursts. Any idea what we can
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
still improve?

guidosch, 2023-03-07:
No longer an issue.

Closed 2023-03-07.

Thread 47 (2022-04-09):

RTC battery status

MeierTobias, 2022-04-09:
Check if the RTC battery has enough power and write it to the status bit

MeierTobias, 2022-09-05:
Obsolete due to #48

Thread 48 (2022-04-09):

Method to use internal RTC

MeierTobias, 2022-04-09:
With time sync over downlink message

guidosch, 2022-04-14:
We use the low power lib to make a deep sleep when only listening to the GPIO event from the PIR. Does the internal RTC work in deep sleep?

MeierTobias, 2022-04-14:
I had a look at the documentation and the deepSleep mode should not affect the RTC but I have not tested it yet. It's a bit hard to check because the deepSleep messes with the serial connection. So the best way to test this is by sending the timestamp to the ttn and check it there.

MeierTobias, 2022-04-14:
I'll test this on my breadboard after I finished the "allmendtrail-1" counter

MeierTobias, 2022-04-15:
approach: (just a note for myself)

- device sends its local time within the data package
- uplink payload formatter calculates the deviation between the device and the server time and passes the package to the webhook
- the cloud function gets the data package and checks if the deviation is in the acceptable range (+ stores the data)
- if the deviation exceeds the threshold then a downlink message will be enqueued with the needed adjustment parameters

MeierTobias, 2022-08-29:
To do: (note for myself)

- [x] remove external rtc code
- [ ] implement internal rtc
- [ ] add timestamp to data package
- [ ] process timestamp on server and enqueue downlink message
- [ ] extract and apply the deviation information from the downlink message
- [ ] Change the time handler from DateTime to (int)seconds and remove all dependencies of the RTClib.h

MeierTobias, 2022-09-08:
all finished and tested

Closed 2022-09-08.

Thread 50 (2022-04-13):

Improve reconnect methode

MeierTobias, 2022-04-13:
I think the section where the re-connection of the lora module is done may cause problems. (starting from line 417)
- errorCounter is never reset
- LORA_RESET pin is always low

MeierTobias, 2023-11-25:
fixed in #90

Closed 2023-11-25.

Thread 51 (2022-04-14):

Timestamp for health data

guidosch, 2022-04-14:
At the moment the timestamp for the health data is taken from the first counter hit in the timestamp array.

This makes it easy to code the loop and every database entry can be used to sum up couter hits.

On the oder hand the timestamps on the health graph look strange, as the timestamps are not in a periodical order. Can we leave this or should we change it?
https://console.cloud.google.com/functions/details/europe-west6/storeBikeCounterPro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

MeierTobias, 2022-04-14:
But for the second issue I metiond (count=0) I could change the device code so that I sends the current time stamp instead of an empty time array

MeierTobias, 2022-04-15:
I thought again about the synchronization problem #48 and I think to solve this in an elegant way the device should send its current time stamp within every data package. This time stamp could then also be used to display the health data

guidosch, 2022-04-17:
Great idea and already implemented.

Closed 2022-04-17.

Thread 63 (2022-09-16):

PCB v0.2

MeierTobias, 2022-09-16:
Update the PCB with the newest findings.

> RTC
> Measurement accuracy
> Pending issues

Closed 2023-12-09.

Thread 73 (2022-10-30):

Test MKRWAN_v2

guidosch, 2022-10-30:
There is a v2 version available of the MRKWAN lib, may be it solves some of the timing issues we have. More details see:

Name: "MKRWAN_v2"
  Autor: Arduino <support@arduino.cc>
  Maintainer: Arduino <support@arduino.cc>
  Sentence: Support library for MKR WAN 1300/1310 - firmware 1.3.1
  Paragraph: Provides APIs to communicate with LoRa and LoraWAN networks
  Website: http://github.com/arduino-libraries/MKRWAN_v2
  Category: Communication
  Architektur: samd, mbed
  Types: Arduino
  Versions: [1.3.1, 1.3.2]

The currently used lib version is no longer further developed:
Name: "MKRWAN"
  Autor: Arduino <support@arduino.cc>
  Maintainer: Arduino <support@arduino.cc>
  Sentence: Support library for MKR WAN 1300/1310
  Paragraph: Provides APIs to communicate with LoRa and LoRaWAN networks
  Website: http://github.com/arduino-libraries/MKRWAN
  Category: Communication
  Architektur: samd, mbed, mbed_portenta
  Types: Arduino
  Versions: [1.0.0, 1.0.1, 1.0.2, 1.0.3, 1.0.4, 1.0.5, 1.0.6, 1.0.7, 1.0.8, 1.0.9, 1.0.10, 1.0.11, 1.0.12, 1.0.13, 1.0.14, 1.0.15, 1.1.0]

guidosch, 2023-03-07:
No activity in repo for a long time.

Closed 2023-03-07.

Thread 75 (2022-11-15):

Abstraction layer between trail and device

MeierTobias, 2022-11-15:
It would be very nice if we could configure and prepare a device completely without having to know on which trail it will be mounted.
To reach that goal we need to create an abstraction layer between the device id and the trail. (Currently the device id indicates the corresponding trail)
Such a logic could be implemented with the following structure:

- every device has a unique id (this is already the case)
- we create a table to specify all the trails
- we create a connection table that describes which devices were mounted on which trail in a specific time range.

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

That would allow us to simplify the maintenance process by just replacing the old device with a new one and insert a new entry into the `timelineConfig` table.

Sorry 😅 I know it's not a relational database but this was the easiest way for me to describe what kind of behavior I would suggest.

## Probably easier solution:
Another possibility would be to stamp the trail info into the dataset on the db when the data arrives. With that method we only need one lookup table to get the current "device->trail" association and the query could filter directly on the dataset and does not need to join different information.

I think I would prefer this method but it just came to my mind while I was writing this issue so I'll leave the original idea at the top.

guidosch, 2023-03-07:
We agreed on the simpler solution.

MeierTobias, 2023-12-09:
Done in #98

Closed 2023-12-09.

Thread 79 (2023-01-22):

Round battery voltage to calm down graph

guidosch, 2023-01-22:
The voltage level toggels between some micro levels which makes the graph unreadable.

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

MeierTobias, 2023-02-26:
I would suggest to keep as much information as possible in the database for future debugging issues. (Also a voltage step discretization of less than 0.1V is necessary to determine the battery level.)

One possible solution would be to adjust the graph scales to a fix range.
- Bat. volt. 3V - 4.2V
- Bat. level 0% - 100%)

I think this would tidy up the graph enough to make it better readable.

guidosch, 2023-02-27:
Scaltes to fixed range did the trick.

Closed 2023-02-27.

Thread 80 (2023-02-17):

Entries in DB with date 1970-01-20

guidosch, 2023-02-17:
There are many entries in the DB with timestamp=0. Couting showed something like 30 entires only for antennentrail-1.
We may should also send the timestamp from TTN to have an idea when this happens.

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

guidosch, 2023-02-17:
Dates are not 0 but 1970-01-20, hmmm even more strange.

guidosch, 2023-02-18:
Not only Antennentrail but also all the others with latest software version.

MeierTobias, 2023-02-26:
I think this problem is already solved.
The first package of the device is the time synchronization message. This contains a wrong timestamp (uninitialized) which triggers the cloud function to send a downlink message with the correction parameter. I updated the cloud function to check if the received message is a sync message and if so to not save it into the DB. But I think this change was applied a few weeks after the software update due to the lack of permissions to edit the cloud functions.
I think these values are artifacts from that period where the cloud function did not handle that special case.

So I would say it is save to delete these entries.

MeierTobias, 2023-02-26:
Related fix #62

guidosch, 2023-02-26:
Deleted timestamps with year 1970. Closing issue.

Closed 2023-02-26.

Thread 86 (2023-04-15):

vs-code setup

MeierTobias, 2023-04-15:
Here is my c_cpp_properties.json file but it's all auto generated by vs-code.
`{
    "version": 4,
    "configurations": [
        {
            "name": "Arduino",
            "compilerPath": "/home/moloch/.arduino15/packages/arduino/tools/arm-none-eabi-gcc/7-2017q4/bin/arm-none-eabi-g++",
            "compilerArgs": [
                "-mcpu=cortex-m0plus",
                "-mthumb",
                "-w",
                "-std=gnu++11",
                "-ffunction-sections",
                "-fdata-sections",
                "-fno-threadsafe-statics",
                "-nostdlib",
                "--param",
                "-fno-rtti",
                "-fno-exceptions"
            ],
            "intelliSenseMode": "gcc-x64",
            "includePath": [
                "/home/moloch/.arduino15/packages/arduino/tools/CMSIS/4.5.0/CMSIS/Include/",
                "/home/moloch/.arduino15/packages/arduino/tools/CMSIS-Atmel/1.2.0/CMSIS/Device/ATMEL/",
                "/home/moloch/.arduino15/packages/arduino/hardware/samd/1.8.13/cores/arduino/api/deprecated",
                "/home/moloch/.arduino15/packages/arduino/hardware/samd/1.8.13/cores/arduino/api/deprecated-avr-comp",
                "/home/moloch/.arduino15/packages/arduino/hardware/samd/1.8.13/cores/arduino",
                "/home/moloch/.arduino15/packages/arduino/hardware/samd/1.8.13/variants/mkrwan1300",
                "/home/moloch/Arduino/libraries/MKRWAN/src",
                "/home/moloch/Arduino/libraries/RTCZero/src",
                "/home/moloch/.arduino15/packages/arduino/hardware/samd/1.8.13/libraries/SPI",
                "/home/moloch/Arduino/libraries/SparkFun_SPI_SerialFlash_Arduino_Library/src",
                "/home/moloch/Arduino/libraries/Arduino_Low_Power/src",
                "/home/moloch/Arduino/libraries/Adafruit_AM2320_sensor_library",
                "/home/moloch/Arduino/libraries/Adafruit_BusIO",
                "/home/moloch/.arduino15/packages/arduino/hardware/samd/1.8.13/libraries/Wire",
                "/home/moloch/Arduino/libraries/Adafruit_Unified_Sensor",
                "/home/moloch/.arduino15/packages/arduino/tools/arm-none-eabi-gcc/7-2017q4/arm-none-eabi/include/c++/7.2.1",
                "/home/moloch/.arduino15/packages/arduino/tools/arm-none-eabi-gcc/7-2017q4/arm-none-eabi/include/c++/7.2.1/arm-none-eabi",
                "/home/moloch/.arduino15/packages/arduino/tools/arm-none-eabi-gcc/7-2017q4/arm-none-eabi/include/c++/7.2.1/backward",
                "/home/moloch/.arduino15/packages/arduino/tools/arm-none-eabi-gcc/7-2017q4/lib/gcc/arm-none-eabi/7.2.1/include",
                "/home/moloch/.arduino15/packages/arduino/tools/arm-none-eabi-gcc/7-2017q4/lib/gcc/arm-none-eabi/7.2.1/include-fixed",
                "/home/moloch/.arduino15/packages/arduino/tools/arm-none-eabi-gcc/7-2017q4/arm-none-eabi/include"
            ],
            "forcedInclude": [
                "/home/moloch/.arduino15/packages/arduino/hardware/samd/1.8.13/cores/arduino/Arduino.h"
            ],
            "cStandard": "c11",
            "cppStandard": "c++11",
            "defines": [
                "F_CPU=48000000L",
                "ARDUINO=10607",
                "ARDUINO_SAMD_MKRWAN1310",
                "ARDUINO_ARCH_SAMD",
                "USE_ARDUINO_MKR_PIN_LAYOUT",
                "__SAMD21G18A__",
                "USB_VID=0x2341",
                "USB_PID=0x8059",
                "USBCON",
                "USB_MANUFACTURER=\"Arduino LLC\"",
                "USB_PRODUCT=\"Arduino MKR WAN 1310\"",
                "USE_BQ24195L_PMIC",
                "VERY_LOW_POWER",
                "__DBL_MIN_EXP__=(-1021)",
                "__HQ_FBIT__=15",
                "__FLT32X_MAX_EXP__=1024",
                "__cpp_attributes=200809",
                "__UINT_LEAST16_MAX__=0xffff",
                "__ARM_SIZEOF_WCHAR_T=4",
                "__ATOMIC_ACQUIRE=2",
                "__SFRACT_IBIT__=0",
                "__FLT_MIN__=1.1754943508222875e-38F",
                "__GCC_IEC_559_COMPLEX=0",
                "__cpp_aggregate_nsdmi=201304",
                "__UFRACT_MAX__=0XFFFFP-16UR",
                "__UINT_LEAST8_TYPE__=unsigned char",
                "__DQ_FBIT__=63",
                "__INTMAX_C(c)=c ## LL",
                "__ULFRACT_FBIT__=32",
                "__SACCUM_EPSILON__=0x1P-7HK",
                "__CHAR_BIT__=8",
                "__USQ_IBIT__=0",
                "__UINT8_MAX__=0xff",
                "__ACCUM_FBIT__=15",
                "__WINT_MAX__=0xffffffffU",
                "__FLT32_MIN_EXP__=(-125)",
                "__cpp_static_assert=200410",
                "__USFRACT_FBIT__=8",
                "__ORDER_LITTLE_ENDIAN__=1234",
                "__SIZE_MAX__=0xffffffffU",
                "__ARM_ARCH_ISA_ARM=1",
                "__WCHAR_MAX__=0xffffffffU",
                "__LACCUM_IBIT__=32",
                "__DBL_DENORM_MIN__=double(4.9406564584124654e-324L)",
                "__GCC_ATOMIC_CHAR_LOCK_FREE=1",
                "__GCC_IEC_559=0",
                "__FLT32X_DECIMAL_DIG__=17",
                "__FLT_EVAL_METHOD__=0",
                "__cpp_binary_literals=201304",
                "__LLACCUM_MAX__=0X7FFFFFFFFFFFFFFFP-31LLK",
                "__FLT64_DECIMAL_DIG__=17",
                "__GCC_ATOMIC_CHAR32_T_LOCK_FREE=1",
                "__FRACT_FBIT__=15",
                "__cpp_variadic_templates=200704",
                "__UINT_FAST64_MAX__=0xffffffffffffffffULL",
                "__SIG_ATOMIC_TYPE__=int",
                "__UACCUM_FBIT__=16",
                "__DBL_MIN_10_EXP__=(-307)",
                "__FINITE_MATH_ONLY__=0",
                "__ARMEL__=1",
                "__cpp_variable_templates=201304",
                "__LFRACT_IBIT__=0",
                "__GNUC_PATCHLEVEL__=1",
                "__FLT32_HAS_DENORM__=1",
                "__LFRACT_MAX__=0X7FFFFFFFP-31LR",
                "__UINT_FAST8_MAX__=0xffffffffU",
                "__has_include(STR)=__has_include__(STR)",
                "__DEC64_MAX_EXP__=385",
                "__INT8_C(c)=c",
                "__INT_LEAST8_WIDTH__=8",
                "__UINT_LEAST64_MAX__=0xffffffffffffffffULL",
                "__SA_FBIT__=15",
                "__SHRT_MAX__=0x7fff",
                "__LDBL_MAX__=1.7976931348623157e+308L",
                "__FRACT_MAX__=0X7FFFP-15R",
                "__UFRACT_FBIT__=16",
                "__UFRACT_MIN__=0.0UR",
                "__UINT_LEAST8_MAX__=0xff",
                "__GCC_ATOMIC_BOOL_LOCK_FREE=1",
                "__UINTMAX_TYPE__=long long unsigned int",
                "__LLFRACT_EPSILON__=0x1P-63LLR",
                "__DEC32_EPSILON__=1E-6DF",
                "__FLT_EVAL_METHOD_TS_18661_3__=0",
                "__CHAR_UNSIGNED__=1",
                "__UINT32_MAX__=0xffffffffUL",
                "__GXX_EXPERIMENTAL_CXX0X__=1",
                "__ULFRACT_MAX__=0XFFFFFFFFP-32ULR",
                "__TA_IBIT__=64",
                "__LDBL_MAX_EXP__=1024",
                "__WINT_MIN__=0U",
                "__INT_LEAST16_WIDTH__=16",
                "__ULLFRACT_MIN__=0.0ULLR",
                "__SCHAR_MAX__=0x7f",
                "__WCHAR_MIN__=0U",
                "__INT64_C(c)=c ## LL",
                "__DBL_DIG__=15",
                "__GCC_ATOMIC_POINTER_LOCK_FREE=1",
                "__LLACCUM_MIN__=(-0X1P31LLK-0X1P31LLK)",
                "__SIZEOF_INT__=4",
                "__SIZEOF_POINTER__=4",
                "__GCC_ATOMIC_CHAR16_T_LOCK_FREE=1",
                "__USACCUM_IBIT__=8",
                "__USER_LABEL_PREFIX__",
                "__STDC_HOSTED__=1",
                "__LDBL_HAS_INFINITY__=1",
                "__LFRACT_MIN__=(-0.5LR-0.5LR)",
                "__HA_IBIT__=8",
                "__FLT32_DIG__=6",
                "__TQ_IBIT__=0",
                "__FLT_EPSILON__=1.1920928955078125e-7F",
                "__APCS_32__=1",
                "__GXX_WEAK__=1",
                "__SHRT_WIDTH__=16",
                "__USFRACT_IBIT__=0",
                "__LDBL_MIN__=2.2250738585072014e-308L",
                "__FRACT_MIN__=(-0.5R-0.5R)",
                "__DEC32_MAX__=9.999999E96DF",
                "__DA_IBIT__=32",
                "__ARM_SIZEOF_MINIMAL_ENUM=1",
                "__FLT32X_HAS_INFINITY__=1",
                "__INT32_MAX__=0x7fffffffL",
                "__UQQ_FBIT__=8",
                "__INT_WIDTH__=32",
                "__SIZEOF_LONG__=4",
                "__UACCUM_MAX__=0XFFFFFFFFP-16UK",
                "__UINT16_C(c)=c",
                "__PTRDIFF_WIDTH__=32",
                "__DECIMAL_DIG__=17",
                "__LFRACT_EPSILON__=0x1P-31LR",
                "__FLT64_EPSILON__=2.2204460492503131e-16F64",
                "__ULFRACT_MIN__=0.0ULR",
                "__INTMAX_WIDTH__=64",
                "__FLT64_MIN_EXP__=(-1021)",
                "__has_include_next(STR)=__has_include_next__(STR)",
                "__LDBL_HAS_QUIET_NAN__=1",
                "__ULACCUM_IBIT__=32",
                "__FLT64_MANT_DIG__=53",
                "__UACCUM_EPSILON__=0x1P-16UK",
                "__GNUC__=7",
                "__ULLACCUM_MAX__=0XFFFFFFFFFFFFFFFFP-32ULLK",
                "__GXX_RTTI=1",
                "__cpp_delegating_constructors=200604",
                "__HQ_IBIT__=0",
                "__FLT_HAS_DENORM__=1",
                "__SIZEOF_LONG_DOUBLE__=8",
                "__BIGGEST_ALIGNMENT__=8",
                "__STDC_UTF_16__=1",
                "__FLT64_MAX_10_EXP__=308",
                "__GNUC_STDC_INLINE__=1",
                "__DQ_IBIT__=0",
                "__FLT32_HAS_INFINITY__=1",
                "__DBL_MAX__=double(1.7976931348623157e+308L)",
                "__ULFRACT_IBIT__=0",
                "__cpp_raw_strings=200710",
                "__INT_FAST32_MAX__=0x7fffffff",
                "__DBL_HAS_INFINITY__=1",
                "__INT64_MAX__=0x7fffffffffffffffLL",
                "__ACCUM_IBIT__=16",
                "__DEC32_MIN_EXP__=(-94)",
                "__THUMB_INTERWORK__=1",
                "__INTPTR_WIDTH__=32",
                "__LACCUM_MAX__=0X7FFFFFFFFFFFFFFFP-31LK",
                "__FLT32X_HAS_DENORM__=1",
                "__INT_FAST16_TYPE__=int",
                "__LDBL_HAS_DENORM__=1",
                "__cplusplus=201402L",
                "__cpp_ref_qualifiers=200710",
                "__DEC128_MAX__=9.999999999999999999999999999999999E6144DL",
                "__INT_LEAST32_MAX__=0x7fffffffL",
                "__ARM_PCS=1",
                "__DEC32_MIN__=1E-95DF",
                "__ACCUM_MAX__=0X7FFFFFFFP-15K",
                "__DEPRECATED=1",
                "__cpp_rvalue_references=200610",
                "__DBL_MAX_EXP__=1024",
                "__USACCUM_EPSILON__=0x1P-8UHK",
                "__WCHAR_WIDTH__=32",
                "__FLT32_MAX__=3.4028234663852886e+38F32",
                "__DEC128_EPSILON__=1E-33DL",
                "__SFRACT_MAX__=0X7FP-7HR",
                "__FRACT_IBIT__=0",
                "__PTRDIFF_MAX__=0x7fffffff",
                "__UACCUM_MIN__=0.0UK",
                "__UACCUM_IBIT__=16",
                "__FLT32_HAS_QUIET_NAN__=1",
                "__GNUG__=7",
                "__LONG_LONG_MAX__=0x7fffffffffffffffLL",
                "__SIZEOF_SIZE_T__=4",
                "__ULACCUM_MAX__=0XFFFFFFFFFFFFFFFFP-32ULK",
                "__cpp_rvalue_reference=200610",
                "__cpp_nsdmi=200809",
                "__SIZEOF_WINT_T__=4",
                "__LONG_LONG_WIDTH__=64",
                "__cpp_initializer_lists=200806",
                "__FLT32_MAX_EXP__=128",
                "__SA_IBIT__=16",
                "__ULLACCUM_MIN__=0.0ULLK",
                "__cpp_hex_float=201603",
                "__GXX_ABI_VERSION=1011",
                "__UTA_FBIT__=64",
                "__SOFTFP__=1",
                "__FLT_MIN_EXP__=(-125)",
                "__USFRACT_MAX__=0XFFP-8UHR",
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

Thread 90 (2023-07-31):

Code refactoring

MeierTobias, 2023-07-31:
To clean up and modularize the edge device code:

Separate into submodules
- [x] LoRa connection
- [x] Measurement logic (move the whole code into its own class/state machine to decouple from arduino logic)

MeierTobias, 2023-11-25:
The refactored code performs good. I'll put a device into my yard to let it run for a couple of days.

Closed 2023-11-25.

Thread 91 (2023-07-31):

Test other antennas

MeierTobias, 2023-07-31:
Test some other antennas with more gain to see if this helps.
(Additional advantage: pass through connector)

MeierTobias, 2023-11-25:
Antenna test results:
[Arduino Antenna](https://store.arduino.cc/products/dipole-pentaband-waterproof-antenna):
In the attic at my house (horizontal antenna alignment)
|                    |  T1 |  T2 |  T3 | T4 |  T5 | T6 |  T7 |  T8  | T9 | T10 | T11 | T12 | avg |
| ------------ | - |  - |  - |  - |  - |  - |  - |  - | - | - |  - |  - | - |
| RSSI [dBm] |  -119 | -105 | -118 | -105 | -105 | -108 | -103 | -107 | -118 | -118 | -111 | -107 | **-107.5** |
| SNR [dBm] |  -6.5   | -10.25 | -9.25 | -10.5 | -10.25 | -8.5 | -10.75 | -10 | -9.5 | -6.5  | -10.5 | -9 | **-9.04** |

[ANT-868-OC-LG-SMA Antenna](https://eu.mouser.com/ProductDetail/TE-Connectivity-Linx-Technologies/ANT-868-OC-LG-SMA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):
In the attic at my house (vertical antenna alignment)
|                    |  T1 |  T2 |  T3 | T4 |  T5 | T6 |  T7 |  T8  | T9 | T10 | T11 | T12 | avg |
| ------------ | - |  - |  - |  - |  - |  - |  - |  - | - | - |  - |  - | - |
| RSSI [dBm] | -125 | -117 | -119 | -130 | -125 | -125 | -128 | -119 | -120 | -119 | -126 | -128 | **-121.6** |
| SNR [dBm] | -12.5 | -10.5 | -11.5 | -16.2 | -12.2 | -13.5 | -10.5 | -11.8 | -11.8 | -9.8 | -11.8 | -12.5 | **-11.8** |

25.6 times worse than the Arduino antenna

[ANT-8/9-SPNF2 Antenna](https://eu.mouser.com/ProductDetail/TE-Connectivity-Linx-Technologies/ANT-8-9-SPNF2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)
In the attic at my house (vertical antenna alignment)
|                    |  T1 |  T2 |  T3 | T4 |  T5 | T6 |  T7 |  T8  | T9 | T10 | T11 | T12 | avg |
| ------------ | - |  - |  - |  - |  - |  - |  - |  - | - | - |  - |  - | - |
| RSSI [dBm] | -123 | -114 | -112 | -111 | -111 | -108 | -117 | -113 | -117 | -111 | -118 | -105 | **-111.1** |
| SNR [dBm] | -1.75 | 2.5 | -5 | 0.75 | -7 | 1 | -6.75 | -0.5 | -7 | 1.25 | -3.5 | -1.5 | **-1.15** |

The RSSI is similar to the Arduino antenna (a bit worse 2.3-times) but the SNR is 6-times better.

I will mount the ANT-8/9-SPNF2 antenna to a device to get some field measurements and see if this improves the Adlisberg-Trail situation.

Closed 2023-11-25.

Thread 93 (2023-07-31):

Improve LoRa connection logic

MeierTobias, 2023-07-31:
Move the whole connection logic to its own class/state machine and correct the waiting and idle behavior.

If this does not help change to the https://github.com/mcci-catena/arduino-lorawan library which is a high level abstraction of the https://github.com/mcci-catena/arduino-lmic which provides an adapted LoRaWAN-MAC-in-C library (from IBM)

MeierTobias, 2023-08-26:
Antenna test results:
[Arduino Antenna](https://store.arduino.cc/products/dipole-pentaband-waterproof-antenna):
In the attic at my house (vertical alignment)
|                    |  T1 |  T2 |  T3 | T4 |  T5 | T6 |  T7 |  T8  | T9 | T10 | T11 | T12 | avg |
| ------------ | - |  - |  - |  - |  - |  - |  - |  - | - | - |  - |  - | - |
| RSSI [dBm] |  -119 | -105 | -118 | -105 | -105 | -108 | -103 | -107 | -118 | -118 | -111 | -107 | **-107.5** |
| SNR[dBm] |  -6.5   | -10.25 | -9.25 | -10.5 | -10.25 | -8.5 | -10.75 | -10 | -9.5 | -6.5  | -10.5 | -9 | **-9.04** |

guidosch, 2023-09-08:
Below a screen shot of the July on the Adlisberg Trail with fresh loaded batteries. It first was online a few days then offline and then felt again in the endless sending mode and the offline again. Later no more data but the batteries where drained within just a few weeks by doing something...
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

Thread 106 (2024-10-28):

Disable counting / sending data when voltage is below 3.4 volt.

guidosch, 2024-10-28:
Some of the PIR outlier are correlated with low current. Best would be to finish counting and sending if the battery power is very low. Might help as well with not going to low with the battery level to protect the batteries.

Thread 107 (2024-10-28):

Pluggable connector based on tree mount part and device mount

guidosch, 2024-10-28:
It has to be easy to plug but also removing with limited number of hand movement must be possible.

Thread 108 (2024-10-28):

Backend based anomalie detection in counting

guidosch, 2024-10-28:
Idea:
Funktion, die 2d Fit macht von den daten in einem fenster über einen monat/woche und die andere ache der tag. Für alle die kombinationen von tag/summe den mittelwert ausrechnen pro tag/stunde. Eine Matrize mit dem Mittelwert, dann aber das glieche grid noch mit der Standardabweichung rechnen und dann sollte man eine idee haben was die wahrsch. für einen ausreisser ist.

Das modell nicht fitten über alle daten (80%) dann aber mit dem rest schauen ob das Modell passt und die vorhersagen passen für die restlichen 20% der Daten.

Besser einen Datensatz nehmen, der gut aussieht als mit einem sliding window arbeiten. Vorteil ist, dass man selber bestimmen kann, welche daten das modell trainieren.

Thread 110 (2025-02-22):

STM: Improve State Flow

MeierTobias, 2025-02-22:
Change the main logic flow to a event based architecture and remove the unnecessary Arduino fixes.

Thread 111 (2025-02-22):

STM: Separate Status and Counter Messages

MeierTobias, 2025-02-22:
At the moment each message contains both the device status and the timeseries of counts. If this is separated we could lower the transmission rate (improve the battery lifetime)

Status Message:
Same as before but aggregated over a day and then sent only once per day.

Count Message:
Here we could aggregate the count even further for example in to 10min bins. (Or even more). I think we don't need the current 1 minute accuracy.

I would suggest to only deploy this to the STM devices because we have a somewhat high message loss on the Arduino devices (due to the down-link ack bug in the mkrwan library)

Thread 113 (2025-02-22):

Multiple PIR Sensors per Device

MeierTobias, 2025-02-22:
To improve the measurements we could add a second or third PIR sensor and send the aggregated data like mean and std. which would help to identify problems.

We could also add a function to disable one of the PIR sensors via a down-link message if it seems to be broken.

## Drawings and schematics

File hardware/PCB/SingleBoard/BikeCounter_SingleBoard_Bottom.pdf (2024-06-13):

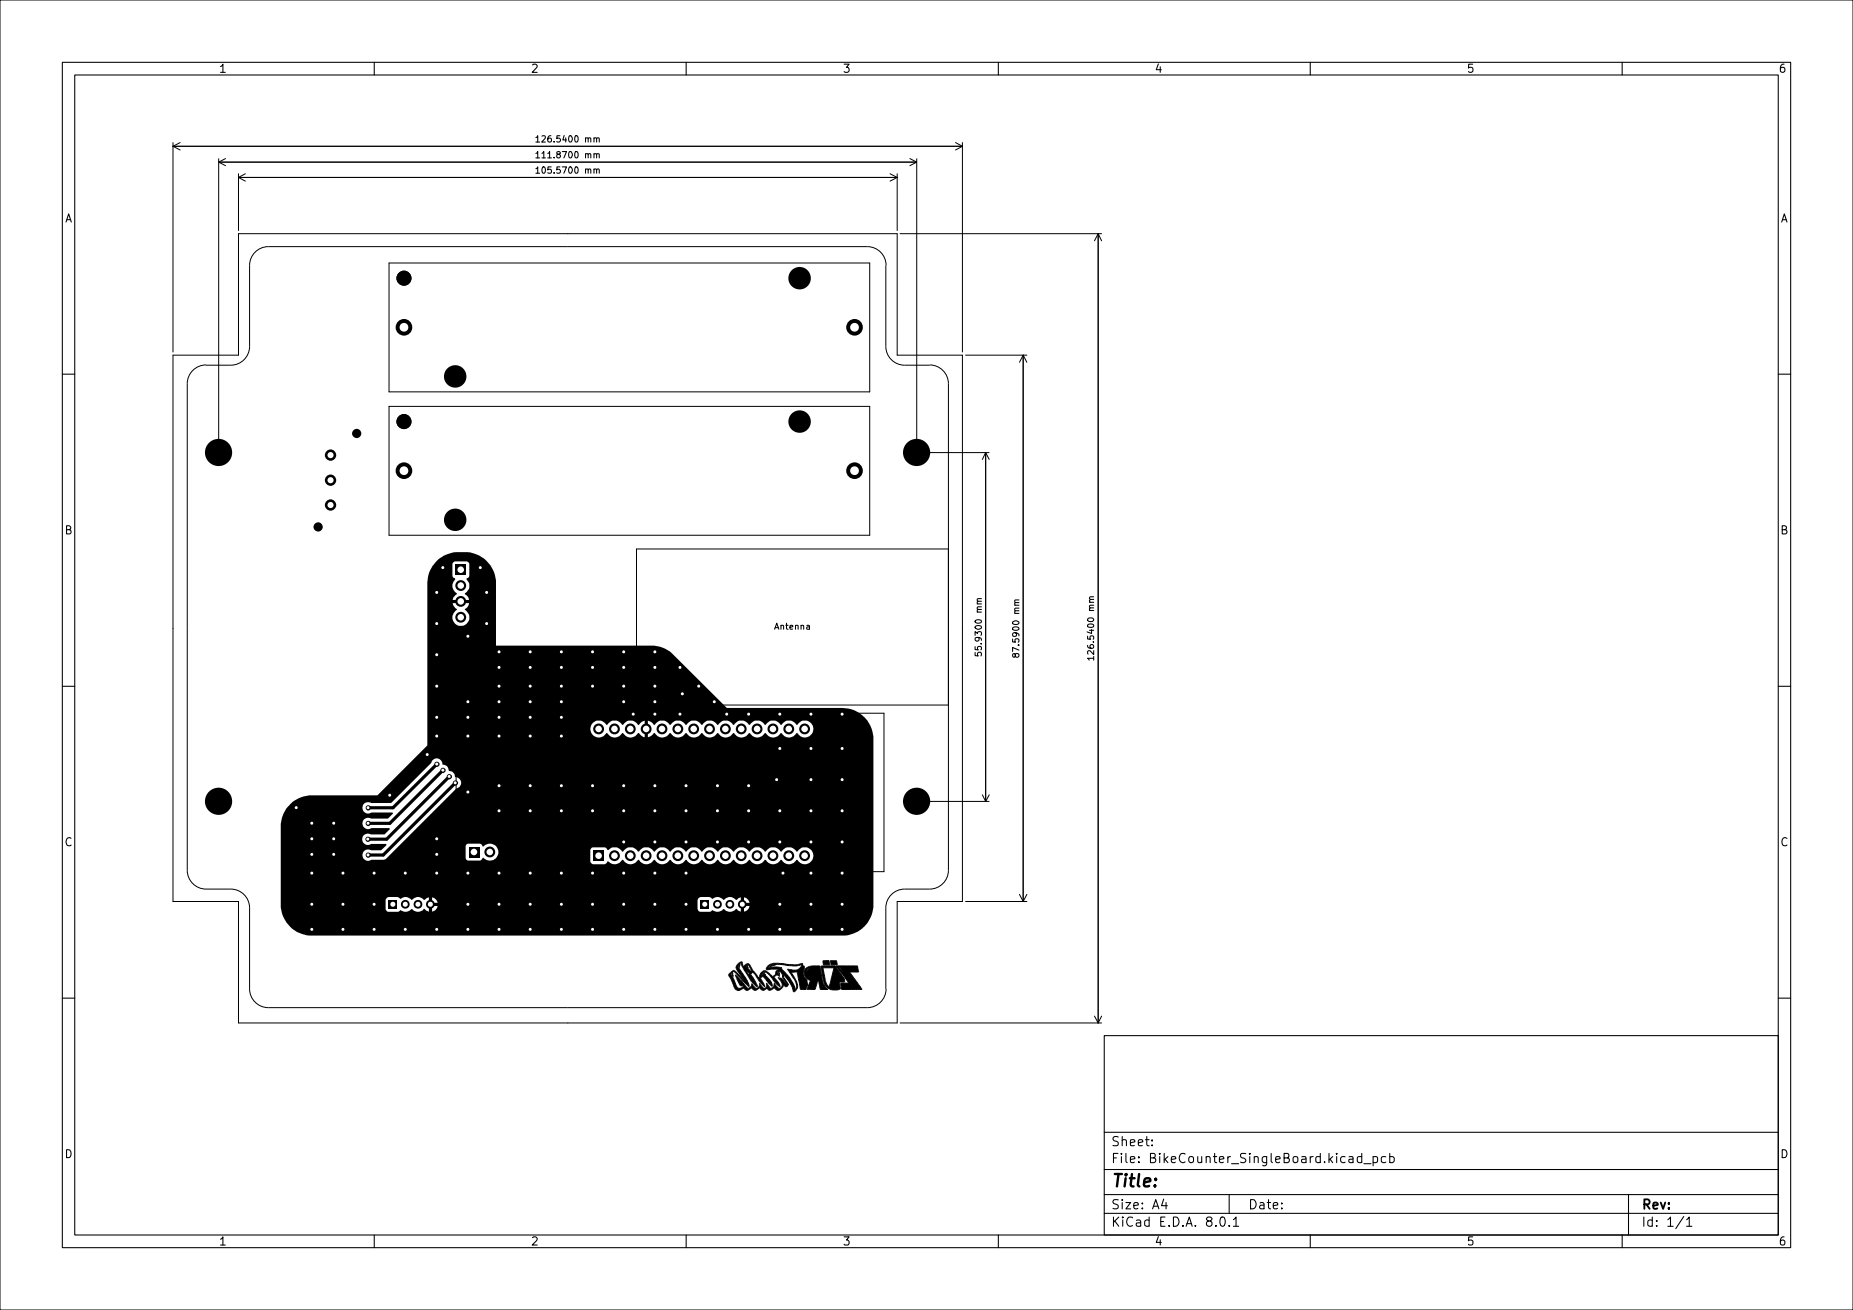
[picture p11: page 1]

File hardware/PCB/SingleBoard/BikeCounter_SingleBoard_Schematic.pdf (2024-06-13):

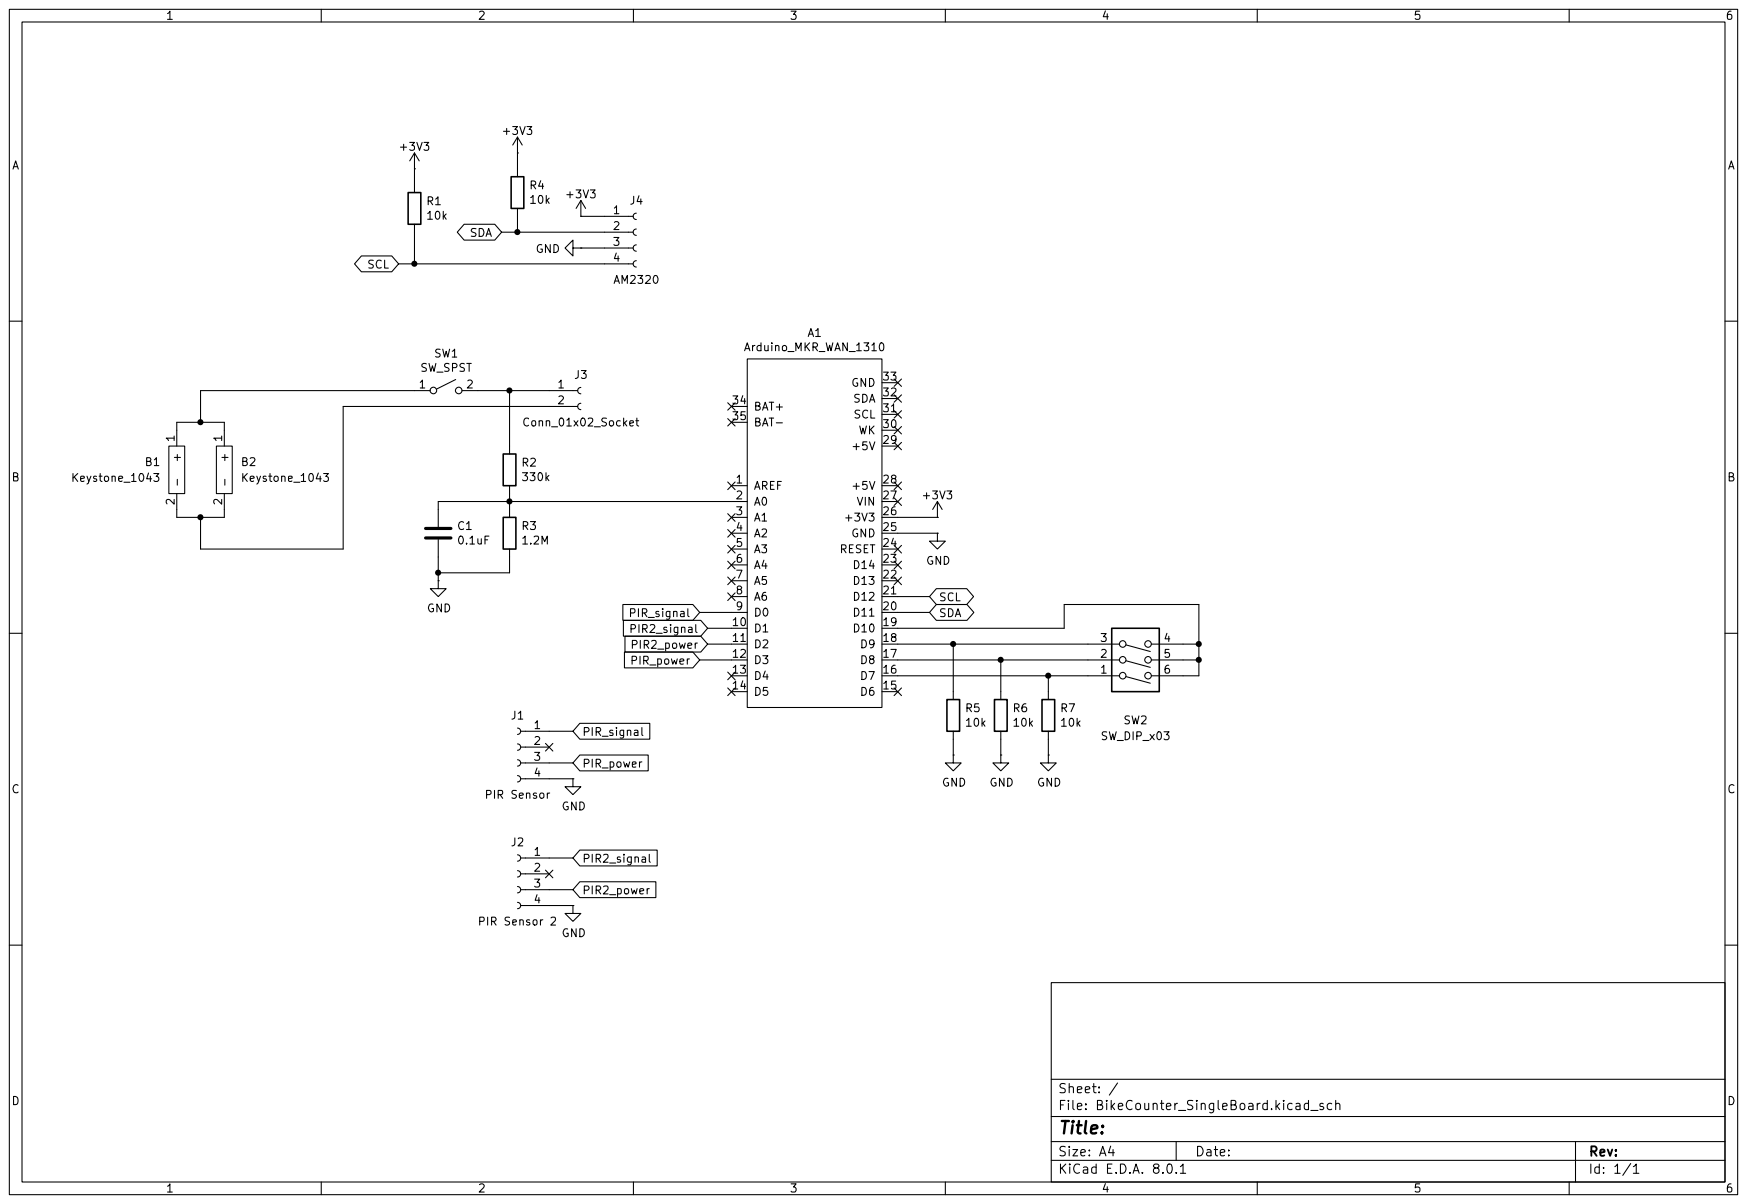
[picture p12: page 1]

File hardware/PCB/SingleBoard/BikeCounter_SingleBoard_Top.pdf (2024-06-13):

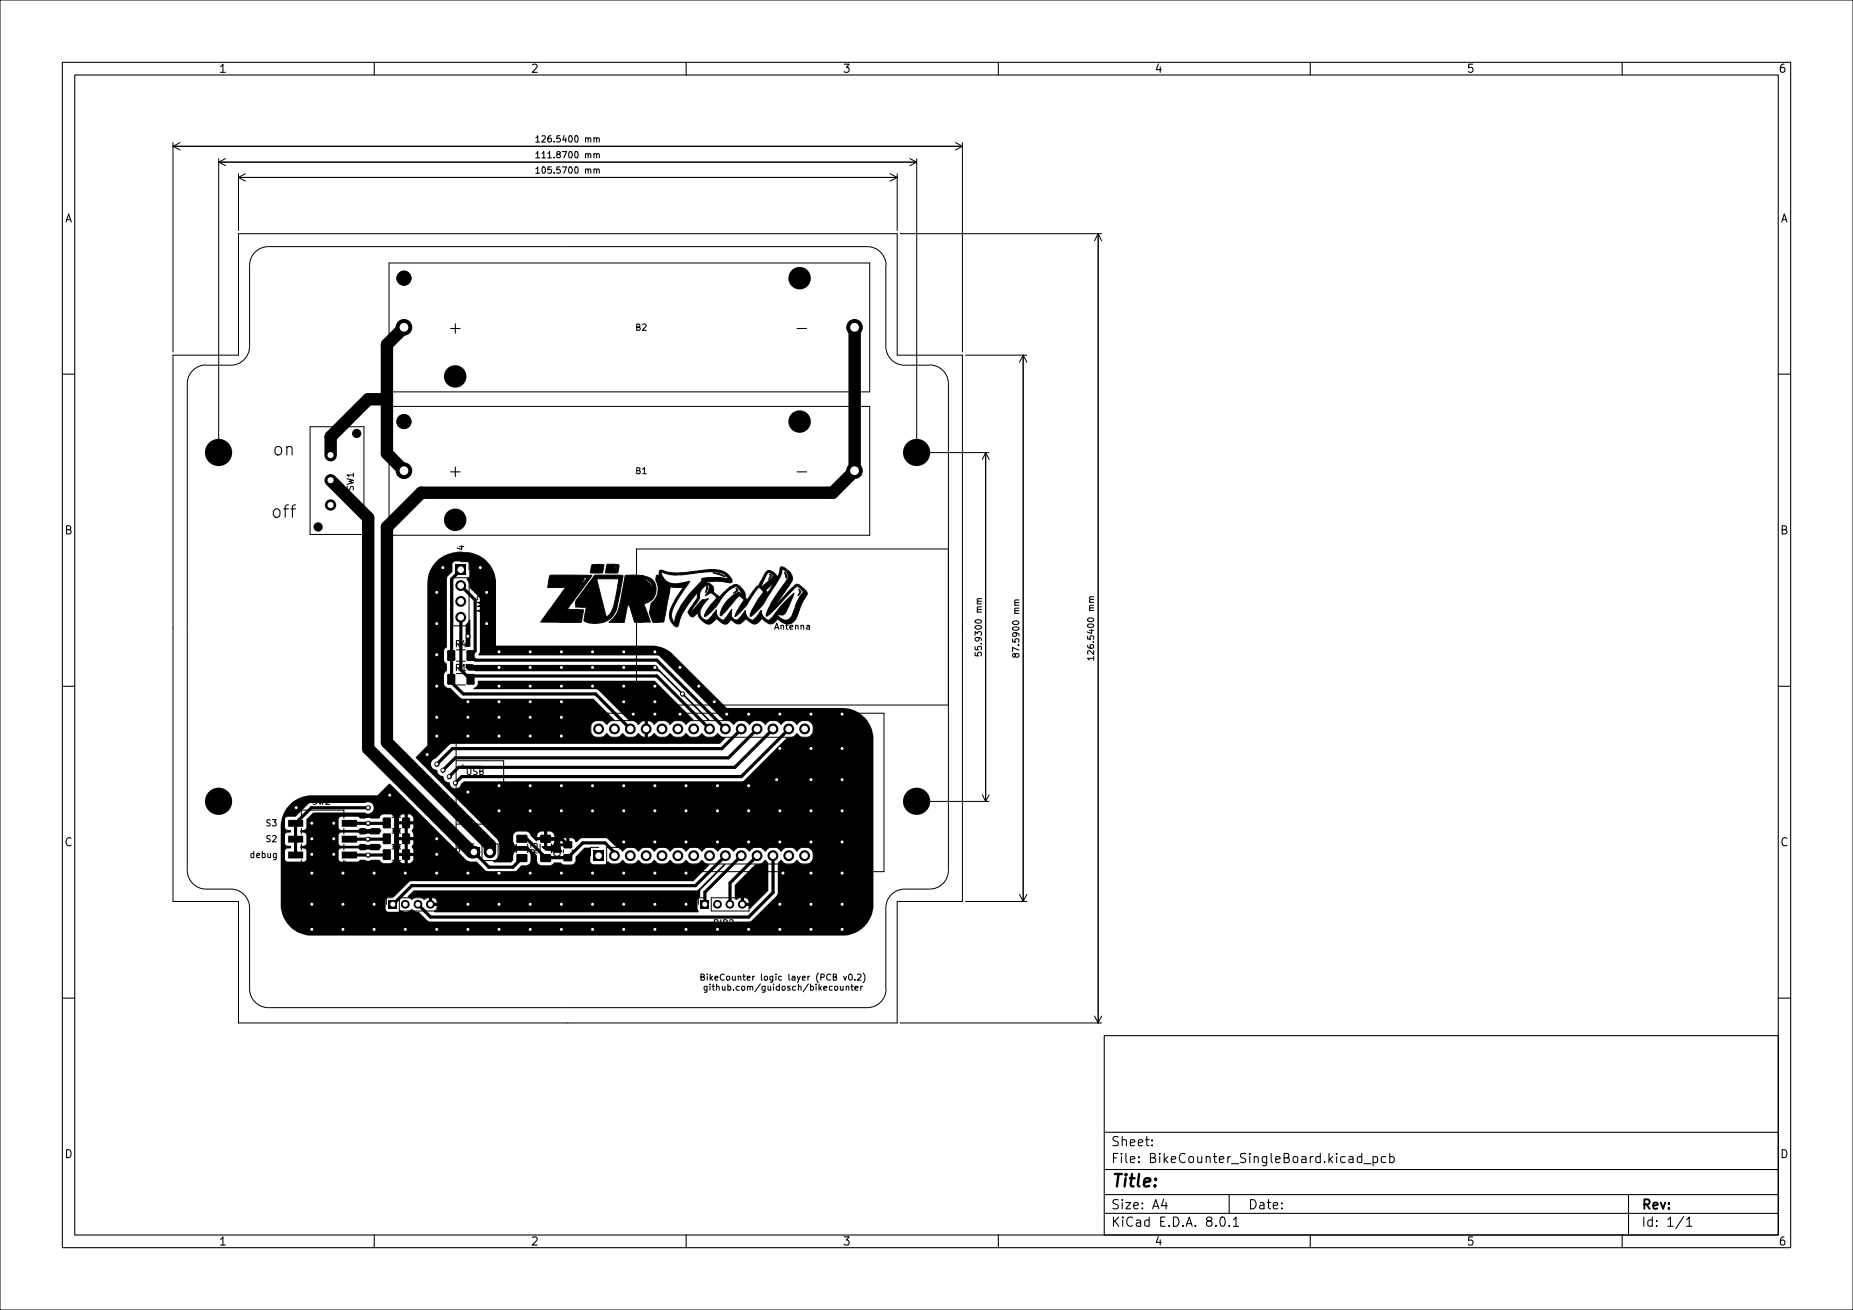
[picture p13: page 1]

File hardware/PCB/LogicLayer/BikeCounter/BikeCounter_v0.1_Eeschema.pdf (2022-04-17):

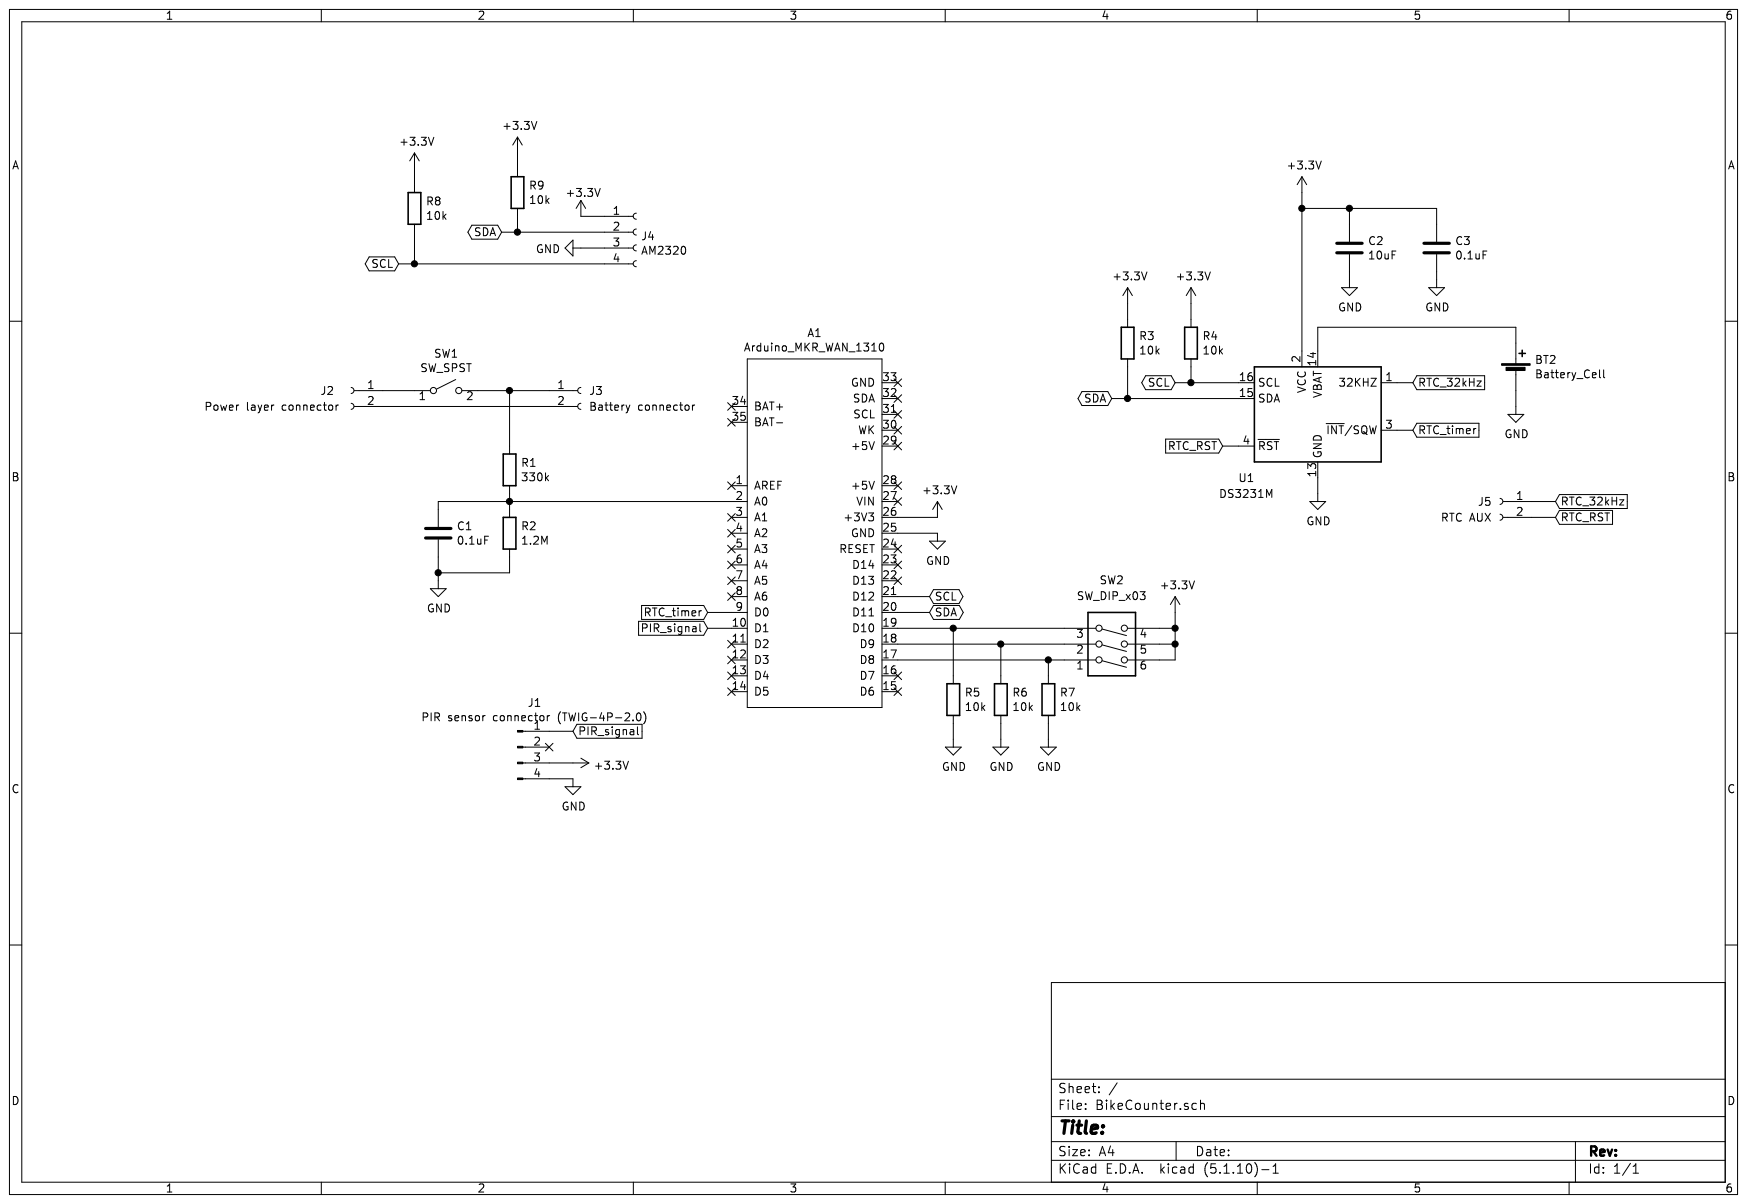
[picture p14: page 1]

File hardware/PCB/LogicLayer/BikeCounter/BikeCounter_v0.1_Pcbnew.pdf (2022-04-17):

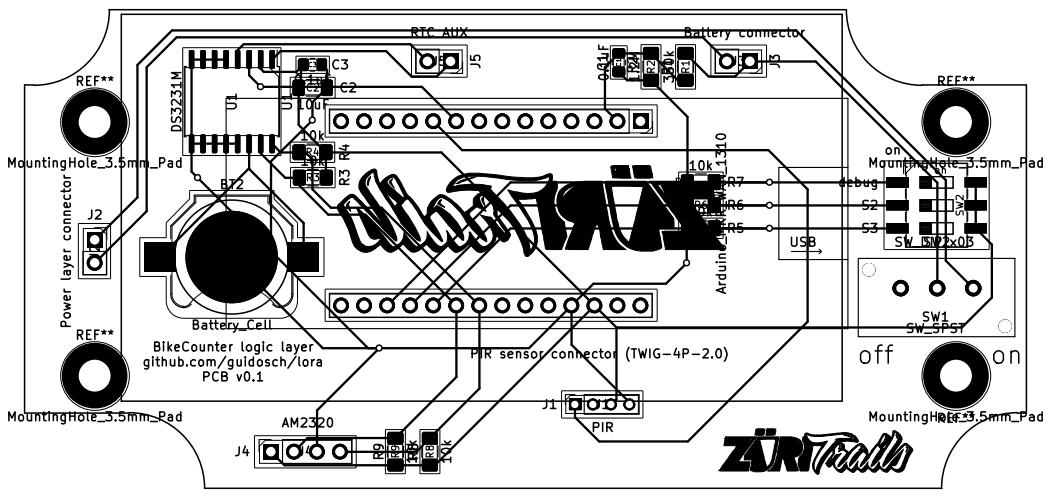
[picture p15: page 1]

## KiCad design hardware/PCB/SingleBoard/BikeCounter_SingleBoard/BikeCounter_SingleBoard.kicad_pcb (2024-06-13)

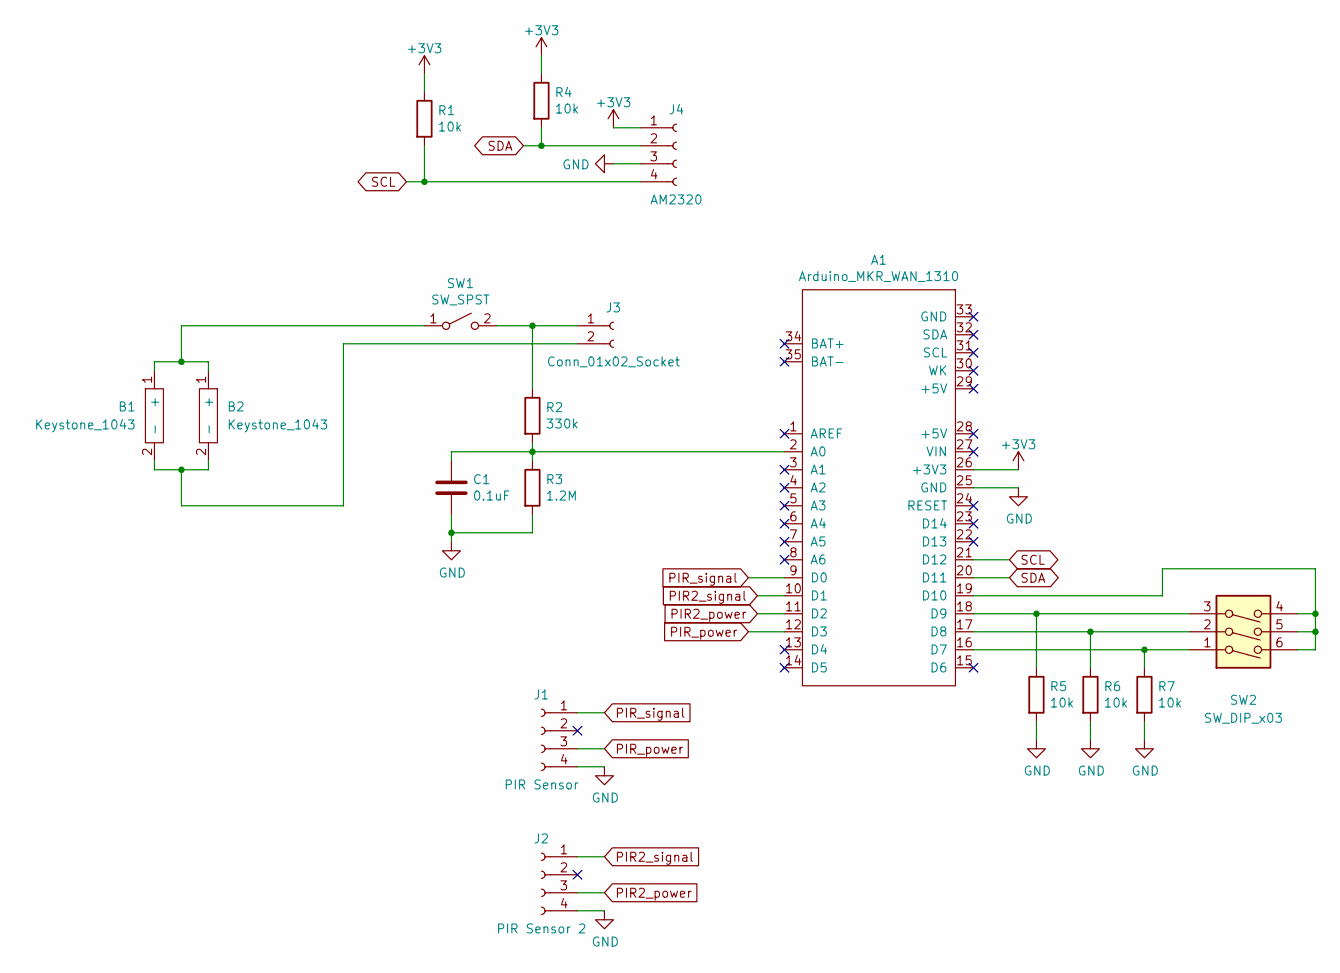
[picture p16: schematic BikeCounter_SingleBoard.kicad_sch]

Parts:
A1: Arduino_MKR_WAN_1310
B1, B2: Keystone_1043; BatteryHolder_Keystone_1043_1x18650
C1: 0.1uF; C_0805_2012Metric_Pad1.18x1.45mm_HandSolder
J1: PIR Sensor; PinSocket_1x04_P2.00mm_Vertical
J2: PIR Sensor 2; PinSocket_1x04_P2.00mm_Vertical
J3: Conn_01x02_Socket; PinSocket_1x02_P2.54mm_Vertical
J4: AM2320; PinSocket_1x04_P2.54mm_Vertical
R1, R4, R5, R6, R7: 10k; R_1206_3216Metric_Pad1.30x1.75mm_HandSolder
R2: 330k; R_1206_3216Metric_Pad1.30x1.75mm_HandSolder
R3: 1.2M; R_1206_3216Metric_Pad1.30x1.75mm_HandSolder
SW1: SW_SPST; Switch_MHS12204
SW2: SW_DIP_x03; SW_DIP_SPSTx03_Slide_6.7x9.18mm_W8.61mm_P2.54mm_LowProfile

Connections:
+3V3: A1.26 (+3V3), J4.1, R1.1, R4.1
GND: A1.25 (GND), C1.2, J1.4, J2.4, J4.3, R3.2, R5.2, R6.2, R7.2
unnamed: A1.2 (A0), C1.1, R2.2, R3.1
unnamed: A1.16 (D7), R7.1, SW2.1
unnamed: A1.17 (D8), R6.1, SW2.2
unnamed: A1.18 (D9), R5.1, SW2.3
unnamed: A1.19 (D10), SW2.4, SW2.5, SW2.6
unnamed: B1.1 (+), B2.1 (+), SW1.1 (A)
unnamed: B1.2 (-), B2.2 (-), J3.2
unnamed: J3.1, R2.1, SW1.2 (B)
PIR2_power: A1.11 (D2), J2.3
PIR2_signal: A1.10 (D1), J2.1
PIR_power: A1.12 (D3), J1.3
PIR_signal: A1.9 (D0), J1.1
SCL: A1.21 (D12), J4.4, R1.2
SDA: A1.20 (D11), J4.2, R4.2

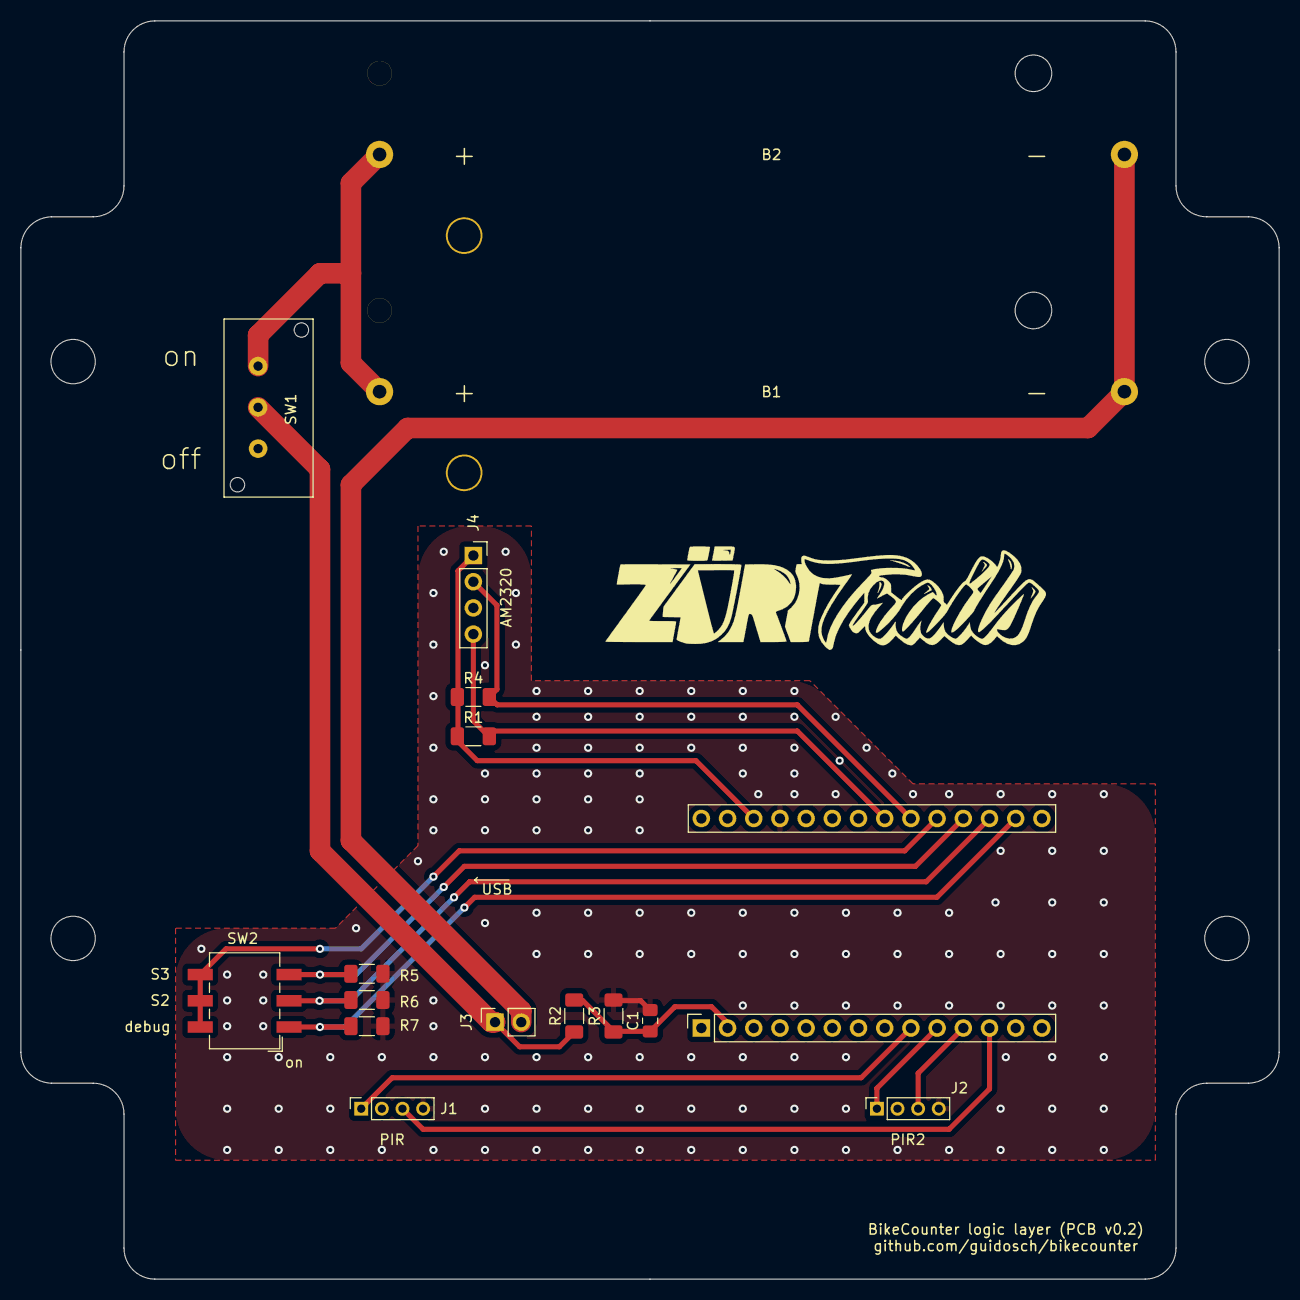
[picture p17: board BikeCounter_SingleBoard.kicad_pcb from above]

Board: 2 copper layers, 122.0 x 122.0 mm, 17 parts (0 on the bottom side), 16 nets.

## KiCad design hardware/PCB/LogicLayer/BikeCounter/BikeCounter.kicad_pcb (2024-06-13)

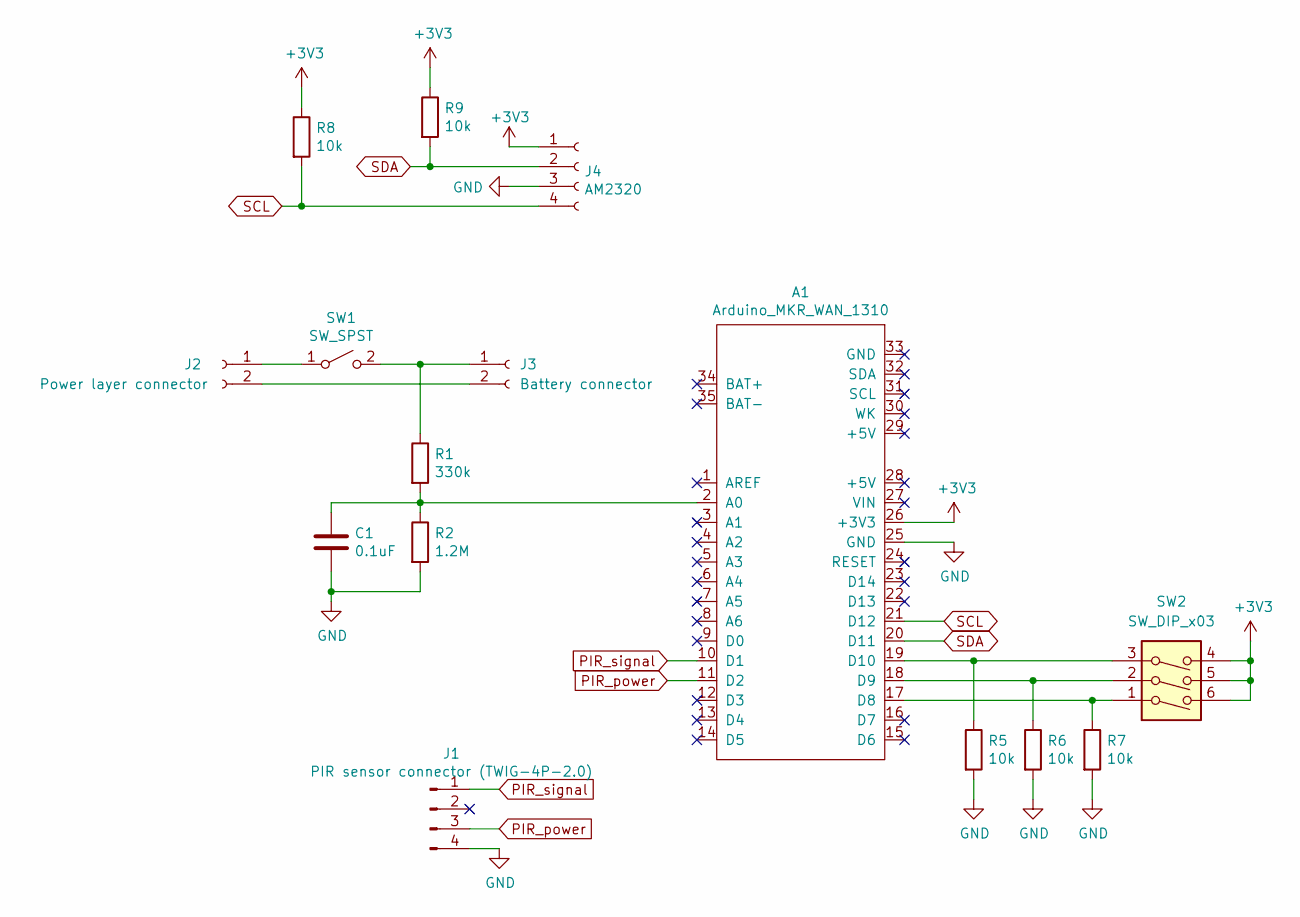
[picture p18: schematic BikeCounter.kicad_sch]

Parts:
A1: Arduino_MKR_WAN_1310
C1: 0.1uF; C_0805_2012Metric_Pad1.18x1.45mm_HandSolder
J1: PIR sensor connector (TWIG-4P-2.0); PinSocket_1x04_P2.00mm_Vertical
J2: Power layer connector; PinSocket_1x02_P2.54mm_Vertical
J3: Battery connector; PinSocket_1x02_P2.54mm_Vertical
J4: AM2320; PinSocket_1x04_P2.54mm_Vertical
R1: 330k; R_1206_3216Metric_Pad1.30x1.75mm_HandSolder
R2: 1.2M; R_1206_3216Metric_Pad1.30x1.75mm_HandSolder
R5, R6, R7, R8, R9: 10k; R_1206_3216Metric_Pad1.30x1.75mm_HandSolder
SW1: SW_SPST; Switch_MHS12204
SW2: SW_DIP_x03; SW_DIP_SPSTx03_Slide_6.7x9.18mm_W8.61mm_P2.54mm_LowProfile

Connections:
+3V3: A1.26 (+3V3), J4.1, R8.1, R9.1, SW2.4, SW2.5, SW2.6
GND: A1.25 (GND), C1.2, J1.4, J4.3, R2.2, R5.2, R6.2, R7.2
unnamed: A1.2 (A0), C1.1, R1.2, R2.1
unnamed: A1.17 (D8), R7.1, SW2.1
unnamed: A1.18 (D9), R6.1, SW2.2
unnamed: A1.19 (D10), R5.1, SW2.3
unnamed: J2.1, SW1.1 (A)
unnamed: J2.2, J3.2
unnamed: J3.1, R1.1, SW1.2 (B)
PIR_power: A1.11 (D2), J1.3
PIR_signal: A1.10 (D1), J1.1
SCL: A1.21 (D12), J4.4, R8.2
SDA: A1.20 (D11), J4.2, R9.2

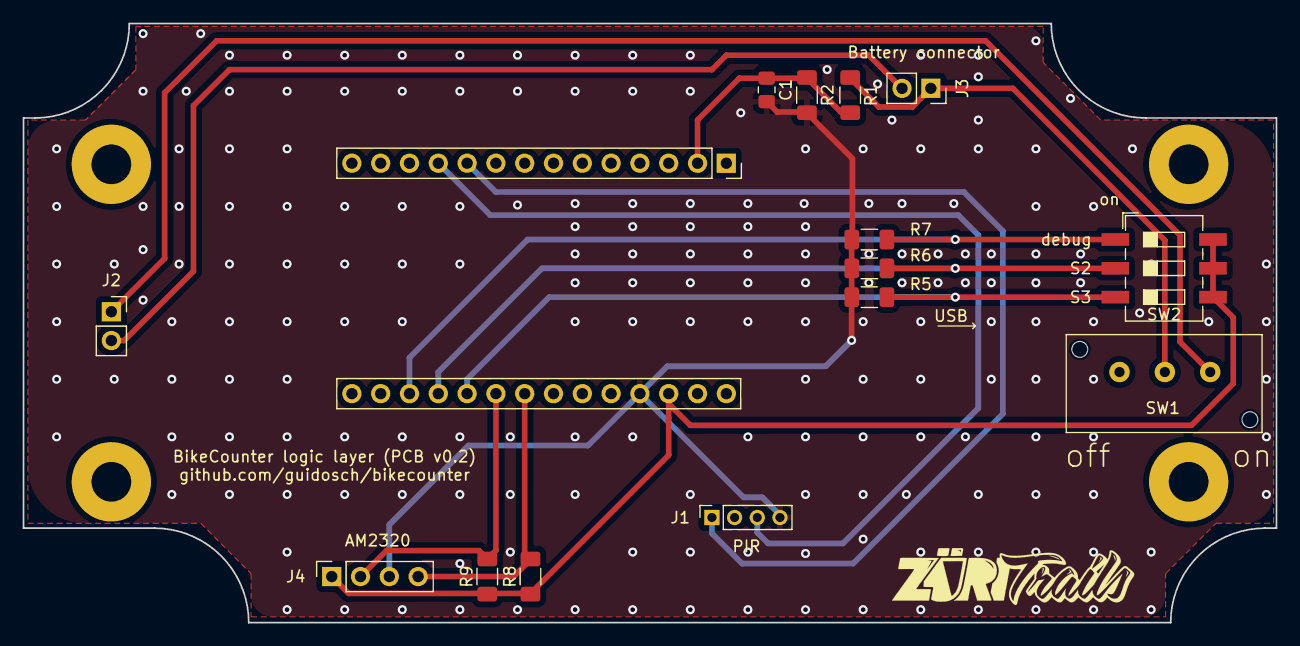
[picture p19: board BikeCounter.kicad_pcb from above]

Board: 2 copper layers, 110.5 x 52.8 mm, 15 parts (0 on the bottom side), 13 nets.

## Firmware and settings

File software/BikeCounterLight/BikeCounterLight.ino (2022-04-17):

#include <MKRWAN.h>
#include "ArduinoLowPower.h"
#include "arduino_secrets.h"

// ----------------------------------------------------
// ------------- Configuration section ----------------
// ----------------------------------------------------

// Set this to activate serial debug messages and to disable deepSleep.
constexpr bool debugFlag = 1;
// The sleep or deepSleep method disables the usb connection which
// leeds to problems with the serial monitor.

// Threshold for non periodic data transmission
const int sendThreshold = 40;
// Sleep intervall (ms)
const u_int32_t sleepTime = 60000ul; // 4h = 14400000ul (4*60*60*1000)
// Max. counts between timer calls (to detect a floating interrupt pin)
const int maxCount = 1000;
// deactivate the onboard LED after the spezified amount of blinks
const int maxBlinks = 50;

// Interrupt pins
const int counterInterruptPin = 1;
// PIR sensor power pin
const int pirPowerPin = 2;
// Used pins (not defined pins will be disabled to save power)
const int usedPins[] = {LED_BUILTIN, counterInterruptPin, pirPowerPin};

// ----------------------------------------------------
// -------------- Declaration section -----------------
// ----------------------------------------------------

// lora modem object and application properties
LoRaModem modem(Serial1);
String appEui = SECRET_APPEUI;
String appKey = SECRET_APPKEY;

// Motion counter value (must be volatile as incremented in IRS)
volatile int counter = 0;
// total counts between timer calls
volatile int totalCounter = 0;
// motion detected flag
volatile bool motionDetected = 0;
// Timer interrupt falg
volatile bool timerCalled = 0;
// Lora data transmission flag
bool isSending = 0;
// Error counter for connection
int errorCounter = 0;
// Error counter for pir-sensor
int pirError = 0;
// Last call of main loop in debug mode
unsigned long lastMillis = 0;

// Blink methode prototype
void blinkLED(int times = 1);

// ----------------------------------------------------
// -------------- Setup section -----------------
// ----------------------------------------------------

void setup()
{
  // setup pin modes
  pinMode(LED_BUILTIN, OUTPUT);
  pinMode(pirPowerPin, OUTPUT);
  disableUnusedPins(usedPins, sizeof(usedPins) / sizeof(usedPins[0]));

  // power the pir sensor
  digitalWrite(pirPowerPin, HIGH);

  if (debugFlag)
  {
    // open serial connection and wait
    Serial.begin(9600);
    while (!Serial)
      ;
    Serial.println("Lora setup started");
  }

  // connect to lora network
  doConnect();

  if (debugFlag)
  {
    Serial.println("Lora setup finished");
  }

  // delay to avoide interference with interrupt pin setup
  delay(200);

  // setup counter interrupt
  pinMode(counterInterruptPin, INPUT_PULLDOWN);
  LowPower.attachInterruptWakeup(counterInterruptPin, onMotionDetected, RISING);
}

// ----------------------------------------------------
// ---------------- Main loop section -----------------
// ----------------------------------------------------

// The main loop gets executed after the device wakes up
// (caused by the timer or the motion detection interrupt)
void loop()
{
  // This statement simulates the sleep/deepSleep methode in debug mode.
  // The reason for not using the sleep or deepSleep method is, that it disables
  // the usb connection which leeds to problems with the serial monitor.
  if (debugFlag)
  {
    // Check if a motion was detected or the sleep time expired
    // (Implemented in a nested if-statement to give the compiler the opportunity
    // to remove the whole outer statement depending on the constexpr debugFlag.)
    if ((motionDetected) || ((millis() - lastMillis) >= sleepTime))
    {
      // Run the main loop once
      lastMillis = millis();
    }
    else
    {
      // Noting happend, continue with the next cycle
      return;
    }
  }

  // check if a motion was detected. If not the sleep periode is expired
  if (motionDetected)
  {
    motionDetected = 0;
    ++counter;
    ++totalCounter;

    blinkLED();

    if (debugFlag)
    {
      Serial.print("Motion detected (current count = ");
      Serial.print(counter);
      Serial.println(')');
    }
  }
  else
  {
    timerCalled = 1;
    totalCounter = 0;
  }

  // check if the floating interrupt pin bug occured
  if ((totalCounter >= maxCount) || (counter > (sendThreshold + 10)))
  {
    ++pirError;
    if (pirError > 2)
    {
      if (debugFlag)
      {
        Serial.println("PIR-sensor error could not me fixed.");
      }
      while (1)
      {
      }
    }
    if (debugFlag)
    {
      Serial.println("Floating interrupt pin detected.");
      Serial.println("Resetting PIR-sensor");
    }
    digitalWrite(pirPowerPin, LOW);
    delay(2000);
    digitalWrite(pirPowerPin, HIGH);
    totalCounter = 0;
  }

  // send the data if the threshold or the periodic time intervall is exceeded
  if (((counter >= sendThreshold) || (timerCalled)) && (!isSending))
  {
    timerCalled = 0;
    blinkLED(2);
    sendData();
  }

  // Put the board to sleep
  if (!debugFlag)
  {
    delay(200);
    LowPower.deepSleep(sleepTime);
  }
}

// ----------------------------------------------------
// --------- Methode implementation section -----------
// ----------------------------------------------------

void onMotionDetected()
{
  if (!isSending)
  {
    motionDetected = 1;
  }
}

// Connects to LoRa network
void doConnect()
{
  isSending = 1;
  if (!modem.begin(EU868))
  {
    if (debugFlag)
    {
      Serial.println("Failed to start module");
    }
    blinkLED(5);
    while (1)
    {
    }
  };
  if (debugFlag)
  {
    Serial.print("Your module version is: ");
    Serial.println(modem.version());
    Serial.print("Your device EUI is: ");
    Serial.println(modem.deviceEUI());
  }
  delay(4000); //increase up to 10s if connectio does not work
  int connected = modem.joinOTAA(appEui, appKey);
  if (!connected)
  {
    if (debugFlag)
    {
      Serial.println("Something went wrong; are you indoor? Move near a window and retry");
    }
    while (1)
    {
      blinkLED();
    }
  }
  modem.minPollInterval(60);
  blinkLED(3);

  // wait for all data transmission to finish
  delay(500);
  isSending = 0;
}

// Sends the acquired data
void sendData()
{
  isSending = 1;
  int err;
  //data is transmitted as Ascii chars
  modem.beginPacket();
  byte payload[1];
  payload[0] = lowByte(counter);
  modem.write(payload, sizeof(payload));
  err = modem.endPacket(false); // true = confirmation request
  if (err > 0)
  {
    if (debugFlag)
    {
      Serial.println("Message sent correctly!");
    }
    counter = 0;
  }
  else
  {
    if (debugFlag)
    {
      Serial.println("Error sending message :(");
    }
    errorCounter++;
    if (errorCounter > 1)
    {
      digitalWrite(LORA_RESET, LOW);
      if (debugFlag)
      {
        Serial.println("Trying to reconnect");
      }
      doConnect();
    }
  }

  // wait for all data transmission to finish
  delay(200);
  isSending = 0;
}

// blinks the on board led
void blinkLED(int times)
{
  // deactivate the onboard LED after the spezified amount of blinks
  static int blinkCount = 0;
  if (blinkCount < maxBlinks)
  {
    ++blinkCount;
    for (int i = 0; i < times; i++)
    {
      delay(100);
      digitalWrite(LED_BUILTIN, HIGH);
      delay(100);
      digitalWrite(LED_BUILTIN, LOW);
    }
  }
}

// Sets all the unused pins to a defined level
// Output and LOW
void disableUnusedPins(const int *const activePins, int size)
{
  for (int i = 0; i < 22; ++i)
  {
    // check if the current pin occures in the pin array
    bool isUsed = false;
    for (int j = 0; j < size; ++j)
    {
      if (activePins[j] == i)
      {
        isUsed = true;
      }
    }
    // if not, set the pin to output and low
    if (!isUsed)
    {
      pinMode(i, OUTPUT);
      digitalWrite(i, LOW);
    }
  }
}

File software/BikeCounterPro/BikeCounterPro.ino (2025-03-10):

#include "config.h"
#include "src/bikeCounter/bikeCounter.hpp"
#include "src/hal/hal_arduino.hpp"

BikeCounter *bc = BikeCounter::getInstance();
HAL *hal = HAL_Arduino::getInstance();

void setup()
{
  bc->injectHal(hal);
  bc->setCounterInterruptPin(0);
  bc->setSwitchPowerPin(10);
  bc->setDebugSwitchPin(7);
  bc->setConfigSwitchPin(8);
  bc->setBatteryVoltagePin(A0);
  bc->setPirPowerPin(3);
  bc->setSyncTimeInterval(120ul); // 2*60 s
  bc->setLedPin(LED_BUILTIN);
  bc->setMaxBlinks(50);
  bc->setMaxCount(1000);

  bc->loop();
}

// The main loop gets executed after the device wakes up
// (caused by the timer or the motion detection interrupt)
void loop()
{
  bc->loop();
  delay(50);
}

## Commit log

2020-03-08 Added visualization for heatpump data.
2020-03-22 Filtering duplicates before adding to database.
2020-03-31 More margin for buttons
2020-05-03 New sensor only provide temp.
    Changed to forward and return temp only.
2020-05-03 Changes for forward/return temp and corrections.
    Some sensors are not accurate, corrected before sending to graph data.
2020-05-08 Added css styles to heatpump monitor.
2020-06-26 Fix bug using forwad temp from last sample.
2020-09-27 Allow to switch for month to year view for all trails.
2020-12-29 Switched to async loading and some UI updates.
2021-01-29 Added Arduino sources.
2021-04-17 Value of Gratweg device was wrong.
2021-09-18 first version of bike counter with simple timer function implemented (TPL5111) and arduino file convention (folder name = file name) applied
2021-09-23 timer to pro version added
2021-09-23 battery level measurement added
2021-09-23 Data package overview added
    [DataPackage.xlsx]
2021-09-23 Solution for continous sending bug implemented
    [BikeCounterPro.ino]
2021-09-23 Code from interrupts removed
2021-09-25 timer reset issue fixed
    [BikeCounterPro.ino]
2021-09-25 Simpler solution for continous sending bug implemented
    [BikeCounterPro.ino]
2021-09-26 Decoding example added
    [DataPackage.xlsx]
2021-09-26 folder renamed and PCB project started
    [BikeCounter.kicad_pcb, BikeCounter.sch, DataPackage.xlsx]
2021-10-03 package size to data size adapted and timer interrupt improved
2021-10-03 motion interrupt improved
2021-10-04 PCB schematic started
2021-10-05 First version of circuit diagram finished
    [BikeCounter.sch]
2021-10-10 PCB v0.1 finished
    [BikeCounter.kicad_pcb, BikeCounter.sch]
2021-10-19 Migrated to TTN V3 payload format and added sample data.
2021-10-29 BikeCounterLight: Timer changed to "LowPower sleep interval" implementation
2021-10-29 More logout in sample data parser
2021-10-29 BikeCounterLight: floating interrupt pin detection
2021-10-30 Data package overview updated
    [DataPackage.xlsx]
2021-10-30 PIR-sensor reset logic implemented
    [BikeCounterLight.ino]
2021-10-30 Deactivation of the onboard LED after a spezific amount of blinks
2021-11-04 data package information updated
    [DataPackage.xlsx]
2021-11-13 temperature and humidity sensor readings implemented
    [DataPackage.xlsx]
2021-11-28 PCB layout splitted into power and logic layer
    [BikeCounter.kicad_pcb, BikeCounter.sch, PowerLayer.kicad_pcb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]
2021-12-04 PowerLayer PCB batterys polarization label added
    [PowerLayer.kicad_pcb]
2021-12-04 rtc behavior bug fixed
    [DataPackage.xlsx]
2021-12-04 Data package time array bug fixed and example decoding added
    [DataPackage.xlsx]
2021-12-04 Humidity sensor to pcb added
    [BikeCounter.kicad_pcb, BikeCounter.sch]
2021-12-04 CAD files generated and assembly started
    [BikeCounter.prt, BikeCounter_PowerLayer.prt]
2021-12-12 Final casing selected and PCB rearranged to fit into the casing
    [BikeCounter.kicad_pcb, BikeCounter.sch, PowerLayer.kicad_pcb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]
2021-12-13 PCB adjusted and BOM started
    [BOM_v0.1_r1.xlsx, BikeCounter.kicad_pcb, PowerLayer.kicad_pcb]
2021-12-13 BOM finished and Gerber files created
    [BOM_v0.1_r1.xlsx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]
2021-12-23 PDFs of schematics created
    [BOM_v0.1_r1.xlsx]
2022-01-05 payload formatter and BOM updated
    [BOM_v0.1_r1.xlsx]
2022-01-05 dip switches implemented
2022-01-09 PIR-sensor disabled during data transmission and minor spelling errors corrected
    [BikeCounterPro.ino, dataPackage.hpp]
2022-01-10 Battery level changed to battery voltage in data package
    [DataPackage.xlsx]
2022-01-30 timerSchedule class finished
2022-03-13 BOM updated
    [BOM_v0.1_r1.xlsx, DataPackage.xlsx]
2022-03-25 timerSchedule unit tests finished
    [BOM_v0.1_r1.xlsx]
2022-04-08 timerSchedule into pro version added
2022-04-09 Hardware and software version index added
    [DataPackage.xlsx]
2022-04-10 Adjusted sample data to new format.
2022-04-13 ACK flag to lora package added and RTC reset time to UTC changed
    [BikeCounterPro.ino]
2022-04-13 commit id to sw version table added
    [DataPackage.xlsx]
2022-04-18 temp. solution for deviceTransmissionTime in uplink formatter addad
2022-08-29 usage of internal rtc and device time transmission implemented
    [DataPackage.xlsx]
2022-09-02 implementation of DateTime classes from RTClib replaced with ctime structs to remove dependency of RTClib
    [BikeCounterPro.ino, dataPackage.hpp]
2022-09-02 time synchronization properties to payload formatter added
    [DataPackage.xlsx]
2022-09-02 downlink and time drift decoding implemented
    [BikeCounterPro.ino]
2022-09-05 time sync bug fixed and downlink post request example script created
    [DataPackage.xlsx]
2022-09-07 time sync bugs fixed
    [BikeCounterPro.ino]
2022-09-15 rtc initialization bug fixed and payload formatter updated
    [DataPackage.xlsx]
2022-09-15 software version commit tag in DataPackage.xlsx updated
    [DataPackage.xlsx]
2022-09-15 files relocated
    [DataPackage.xlsx]
2022-09-16 pcb image added
2022-10-19 timer call corrected
2022-10-20 default calculation of decharge curve added
    [DataPackage.xlsx]
2022-10-20 rounding of battery level in uplink formatter added
2022-10-20 timer bug fixed
2022-10-21 fixed another timer bug
    [BikeCounterPro.ino]
2022-10-21 temp. fix for battery level in uplinkformatter added
2022-10-23 timeSchedule class bug fixed
    [BikeCounterPro.ino]
2022-12-27 timerSchedule implementation changed from c_time to chrono and date.h
2023-06-05 sync call sleep time bug fixed
    [BikeCounterPro.ino]
2023-07-26 version updated
    [DataPackage.xlsx]
2023-11-24 connection status bug fixed
    [bikeCounter.cpp]
2023-11-25 motion and logger bugs fixed
    [bikeCounter.cpp]
2023-11-25 first version of error handling finished
    [BikeCounterPro.ino, bikeCounter.cpp]
2023-11-26 google cloud function updated to support the device-trail connection collection
2023-11-26 case separation for dev app added
2023-12-02 PIR shutdown and error handling improved
    [bikeCounter.cpp]
2023-12-07 motion interrupt bug fixed
    [bikeCounter.cpp]
2023-12-09 reset of lora module removed to avoid unwanted behavior
    [bikeCounter.cpp]
2023-12-09 pcb v0.2 started
    [BikeCounter.kicad_pcb, BikeCounter.kicad_sch]
2023-12-14 blink pattern added to debug deepSleep problem
    [bikeCounter.cpp]
2023-12-29 statusLogger bug fixed and debug output removed
    [bikeCounter.cpp]
2023-12-29 led counter reactivated
2024-01-03 timer interval bug fixed
    [bikeCounter.cpp, dataPackage.hpp]
2024-03-22 single board pcb finished (and old projects updated to KiCad 8)
    [BikeCounter_SingleBoard.kicad_pcb, BikeCounter_SingleBoard.kicad_sch, PowerLayer.kicad_sch]
2024-03-22 Gerber files added and BOM started
    [BOM_v0.2.xlsx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]
2024-03-23 BOM finished
    [BOM_v0.2.xlsx, BikeCounter_SingleBoard.kicad_pcb, BikeCounter_SingleBoard.xlsx]
2024-03-23 old gerber files removed and BOM updated
    [BOM_v0.2.xlsx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]
2024-04-03 gerber files updated
    [BOM_v0.2.xlsx, BikeCounter_SingleBoard.kicad_pcb]
2024-04-24 schematic pdf's created
2024-04-24 switch power pin implemented
2024-06-16 Arduino deps. removed from bikeCounter.hpp
2024-06-22 millis bug fixed
2024-06-22 sw and hw version updated
    [DataPackage.xlsx]
